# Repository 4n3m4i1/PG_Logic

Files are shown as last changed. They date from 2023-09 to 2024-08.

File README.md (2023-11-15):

# ProgrammaGull Logic
Small and open source FPGA development boards for all those still pecking for fries.  

## Hardware
Design files provided for KiCad 7.
  
### PGL Sandpiper
An education focused development platform, full of fun I/O and devices for users to learn the basics of real world FPGA development. The board centers around the Lattice iCE40-UP5k, which itself offers ample BRAM, PSRAM, 8 DSP Blocks, a PLL, and two internal oscillators.

### PGL E3
An iCE40-UP5k SG48 development board and associated programmer board.  
Designed to be embeddable and flexible enough for most projects!  
  
### PGL E6
A small embeddable Lattice iCE40-LP384 aimed at alleviating the overhead incurred when adding glue logic or general PL space into a project.

### PGL E6-NF
The same PGL E6 but with no flash, allowing smaller footprints when accompanied by some external bitstream source (MCU, external flash, other FPGA, etc..)

## Credits
Name: @slurpeecup

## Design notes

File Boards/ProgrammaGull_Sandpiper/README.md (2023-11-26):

# ProgrammaGull Sandpiper
The Sandpiper is a complete educational development platform based on the Lattice UP5K.  
Designed for students in introductory FPGA labs and other interested parties.  
A plethora of user I/O options are integrated, allowing a complete system that can  
be used anywhere with minimal setup.

## Todo
v. Alpha
- Cleanup Layout
- Assess switching PSU
- Serialize Switch Inputs (Par -> Ser)
- Swap GPIO header to manufacturable part
- No ADC Version with 2x6 PMOD
- Add encoder, maybe bring back center DPAD button?
- Consolidate BOM (3x HCS595, discrete PNP and NPN driver for 7 seg)
  
## Errata
v. Alpha
- First board run has reversed UART TX/RX LED orientation (Fixed in KiCad files)
- First board run 7 segment common anode driver transistor bases leak through 74HCS596 input protection diode, all digits are always on.

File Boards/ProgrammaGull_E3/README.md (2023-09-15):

# ProgrammaGull E3
A flexible and light development board based on the iCE40-SG48, designed for use with project icestorm and Apio.

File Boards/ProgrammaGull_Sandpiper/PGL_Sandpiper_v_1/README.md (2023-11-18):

# ProgrammaGull Logic Sandpiper
A small development board intended for introductions to FPGA development and university FPGA labs.  
A Lattice iCE40-UP5k is at the heart of the Sandpiper, offering a plethora of hard peripheral options, as well as adequate logic cells to support somewhat large projects.  
  
## Features
- 8 character 7 segment display (serial access)
- 4 direction DPAD and an additional button
- 6 pin PMOD (or GPIO), 2 GPIO with RC low pass filter aliases allowing an on board PDM DAC output
- Optional 4 input SPI ADC (ADC084S051CIMM)
- RGB LED
- 8 SPST slide switches
- 8 single color LEDs (serial access)
- FT2232HQ interface supporting both programming and PC USB <-> FPGA UART via FTDI VCOM
  
As the UP5k has limited GPIO pins for a general purpose development board serial -> parallel and in the future  
parallel to serial interfaces are implemented for the low speed high pin count I/O (7 segment displays, LED banks, etc..), this is notated by (serial access) next to a feature.  

## Software Support
Once initial prototypes arrive scripts will be released to integrate the Sandpiper into the Apio ecosystem.  
This open source assembly of tools greatly simplifies lint, build, and upload on many FPGA platforms,  
and is highly recommended for introductory users (and advanced users as well.. it's very practical!)  
  
Standard icestick workflows may also be supported, though this has yet to be seen.
  
## Errata
- First run of boards had reversed LEDs on FT2232HQ, this has been fixed in schematic and PCB

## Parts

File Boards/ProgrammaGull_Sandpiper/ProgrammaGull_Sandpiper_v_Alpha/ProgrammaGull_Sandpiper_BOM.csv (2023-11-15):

Designator | Qty | Value | Footprint | LCSC Part Number
C1, C2, C3, C4, C5, C6, C19, C21, C23, C24 | 10 | 1u | 603 | C525331
C8, C9, C11, C13, C14, C16, C18, C20, C22, C26, C28, C29, C31, C32, C34, C36, C37, C40, C41, C43, C44, C46, C47, C48, C50, C52, C54, C55, C56 | 29 | 100n | 603 | C2168880
C10, C12, C15, C17, C25, C27, C30, C33, C35 | 9 | 4u7 | 805 | C2918489
C42, C45, C49, C51, C53 | 5 | 10n | 603 | C57112
D1 | 1 | 1N4148W | SOD-123 | C81598
D2, D3, D4, D5, D6, D7, D8, D9, D11, D12 | 10 | LED | 805 | C2297
D10 | 1 | LED_ABGR | PLCC4 | C2874119
FB1, FB2 | 2 | FerriteBead_Small | 603 | C1002
P1 | 1 | USB_C_Plug_USB2.0 | Connector_USB:USB_C_Receptacle_GCT_USB4105-xx-A_16P_TopMnt_Horizontal | C963411
Q1, Q2, Q3, Q4, Q5, Q6, Q7, Q8 | 8 | MMBT2907 | SOT-23 | C106923
R1, R7, R8, R10, R12, R14, R16, R18, R20, R22, R24, R26, R28, R32, R34, R36, R37, R39, R40, R41, R42, R51, R52, R53, R63, R65, R66, R67, R68, R69, R70, R71, R72, R73, R74 | 35 | 10k | 603 | C25804
R2, R35, R54, R87, R88, R89, R90, R91 | 8 | 680R | 603 | C112310
R3, R4 | 2 | 56k | 603 | C23206
R5, R83, R84 | 3 | 100R | 603 | C22775
R6, R9, R11, R13, R15, R17, R19, R21, R23, R25, R27, R29, R55, R56, R57, R58, R59, R60, R61, R62, R64, R79, R80, R81, R82, R85, R86 | 27 | 220R | 603 | C22962
R33 | 1 | 2k2 | 603 | C4190
R38 | 1 | 12k 1% | 603 | C22790
R43, R44, R45, R46, R47, R48, R49, R50 | 8 | 383R | 603 | C5126195
SW0, SW1, SW2, SW3, SW4, SW5, SW6, SW7 | 8 | SW_Slide | SLW-121586-5A-D | C2887261
SW9, SW10, SW11, SW12, SW14 | 5 | SW_Push | Alps_SKQGAKE010 | C127478
U2 | 1 | SN74LVC1G126DCKR | SC70 | C88039
U3, U12 | 2 | 74HCS596 | TSSOP-16_4.4x5mm_P0.65mm | C2871501
U4 | 1 | MIC5504-1.2YM5 | SOT-23-5 | C81462
U6 | 1 | 93LCxxAxxOT | SOT-23-6 | C190271
U7 | 1 | FT2232HQ | QFN-64-1EP_9x9mm_P0.5mm_EP4.35x4.35mm | C193662
U8, U10 | 2 | Display_7Seg | MHDA3641SRBW | C401125
U13 | 1 | 74AHCS595 | TSSOP-16_4.4x5mm_P0.65mm | C2864509
U14 | 1 | W25Q32JVSS | SOIC-8_5.23x5.23mm_P1.27mm | C179173
U15 | 1 | AMS1117-3.3 | SOT-223-3_TabPin2 | C6186
X1 | 1 | SG-210STF | Oscillator_SMD_SeikoEpson_SG210-4Pin_2.5x2.0mm | C2831468

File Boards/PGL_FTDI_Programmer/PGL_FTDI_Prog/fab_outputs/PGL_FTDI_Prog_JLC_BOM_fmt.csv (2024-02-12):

Designator | Qty | Value | Footprint | LCSC Part Number
C1, C2, C9, C14, C26 | 5 | 1u | Capacitor_SMD:C_0402_1005Metric | C52923
C4, C5, C6, C10, C12, C15, C16, C18, C19, C24, C25 | 11 | 100n | Capacitor_SMD:C_0402_1005Metric | C307331
C7, C8, C11, C13, C17, C27 | 6 | 4u7 | Capacitor_SMD:C_0805_2012Metric | C1779
C22, C23 | 2 | 33p C0G | Capacitor_SMD:C_0402_1005Metric | C1562
D2, D3 | 2 | LED | LED_SMD:LED_0805_2012Metric | C2297
FB1, FB2 | 2 | FerriteBead_Small | Inductor_SMD:L_0603_1608Metric | C1002
P1 | 1 | USB_C_Plug_USB2.0 | Connector_USB:USB_C_Receptacle_GCT_USB4105-xx-A_16P_TopMnt_Horizontal | C963413
R1, R3, R5, R6 | 4 | 10k | Resistor_SMD:R_0603_1608Metric | C25804
R2 | 1 | 2k2 | Resistor_SMD:R_0603_1608Metric | C4190
R4 | 1 | 12k 1% | Resistor_SMD:R_0603_1608Metric | C22790
R7, R8 | 2 | 56k | Resistor_SMD:R_0603_1608Metric | C23206
R11, R14 | 2 | 330R | Resistor_SMD:R_0603_1608Metric | C23151
U1 | 1 | XC6206PxxxMR | Package_TO_SOT_SMD:SOT-23-3 | C5446
U4 | 1 | 93LCxxAxxOT | Package_TO_SOT_SMD:SOT-23-6 | C190271
U5 | 1 | FT2232HQ | Package_DFN_QFN:QFN-64-1EP_9x9mm_P0.5mm_EP4.35x4.35mm | C193662
Y1 | 1 | 12.000 MHz, C9002 | Crystal:Crystal_SMD_3225-4Pin_3.2x2.5mm | C9002

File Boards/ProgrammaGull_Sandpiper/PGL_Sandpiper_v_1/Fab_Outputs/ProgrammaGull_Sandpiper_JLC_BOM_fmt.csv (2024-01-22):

Designator | Qty | Value | Footprint | LCSC Part Number
C1, C2, C3, C4, C5, C6, C19, C21, C23, C24, C41, C43, C44 | 13 | 1u | Capacitor_SMD:C_0603_1608Metric | C15849
C7, C8, C9, C11, C13, C14, C16, C18, C20, C22, C26, C28, C29, C31, C32, C34, C36, C37, C40, C46, C47, C48, C50, C52, C54, C55, C56, C60, C61 | 29 | 100n | Capacitor_SMD:C_0603_1608Metric | C14663
C10, C12, C15, C17, C25, C27, C30, C33, C35, C57, C58, C59 | 12 | 4u7 | Capacitor_SMD:C_0805_2012Metric | C1779
C38, C39, C42, C45, C49, C51, C53 | 7 | 10n | Capacitor_SMD:C_0603_1608Metric | C57112
D1 | 1 | 1N4148W | Diode_SMD:D_SOD-123 | C81598
D2, D3, D4, D5, D6, D7, D8, D9, D11, D12 | 10 | LED | LED_SMD:LED_0805_2012Metric | C2297
D10 | 1 | LED_ABGR | LED_SMD:LED_Cree-PLCC4_2x2mm_CW | C2874119
FB1, FB2 | 2 | FerriteBead_Small | Inductor_SMD:L_0603_1608Metric | C1002
J1 | 1 | Conn_02x14_Odd_Even | Connector_PinSocket_2.54mm:PinSocket_2x14_P2.54mm_Horizontal | C2897434
P1 | 1 | USB_C_Plug_USB2.0 | Connector_USB:USB_C_Receptacle_GCT_USB4105-xx-A_16P_TopMnt_Horizontal | C963411
Q1, Q2, Q3, Q4, Q5, Q6, Q7, Q8 | 8 | S9012 2T1 | Package_TO_SOT_SMD:SOT-23 | C8543
R1, R7, R8, R10, R12, R14, R16, R18, R20, R22, R24, R26, R28, R30, R31, R32, R34, R36, R37, R39, R40, R41, R42, R51, R52, R53, R63, R65, R66, R67, R68, R69, R70, R71, R72, R73, R74, R75, R76, R77, R78, R79, R81 | 43 | 10k | Resistor_SMD:R_0603_1608Metric | C25804
R2, R33, R35, R54, R87, R88, R89, R90, R91 | 9 | 2k2 | Resistor_SMD:R_0603_1608Metric | C4190
R3, R4 | 2 | 56k | Resistor_SMD:R_0603_1608Metric | C23206
R5, R83, R84 | 3 | 100R | Resistor_SMD:R_0603_1608Metric | C22775
R6, R9, R11, R13, R15, R17, R19, R21 | 8 | 220R | Resistor_SMD:R_0603_1608Metric | C22962
R23, R25, R27, R29, R64, R80, R92, R93, R94, R95, R96, R97, R98, R99 | 14 | 220R | Resistor_SMD:R_0402_1005Metric | C25091
R38 | 1 | 12k 1% | Resistor_SMD:R_0603_1608Metric | C22790
R43, R44, R45, R46, R47, R48, R49, R50 | 8 | 390R | Resistor_SMD:R_0603_1608Metric | C23151
R55, R56, R57, R58, R59, R60, R61, R62 | 8 | 400R | Resistor_SMD:R_0603_1608Metric | C23151
R85, R86 | 2 | 330R | Resistor_SMD:R_0603_1608Metric | C23151
SW0, SW1, SW2, SW3, SW4, SW5, SW6, SW7 | 8 | ~ | ProgrammaGull_Logic:SLW-121586-5A-D | C2887261
SW8 | 1 | RotaryEncoder_Switch | Rotary_Encoder:RotaryEncoder_Alps_EC11E-Switch_Vertical_H20mm | C2991196
SW9, SW10, SW11, SW12, SW13 | 5 | SW_Push | ProgrammaGull_Logic:TSC015A05518A | C2888975
U2 | 1 | SN74LVC1G126DCKR | ProgrammaGull_Logic:SC70 | C88039
U3, U12, U13 | 3 | 74HCT595 | Package_DFN_QFN:DHVQFN-16-1EP_2.5x3.5mm_P0.5mm_EP1x2mm | C3303720
U4 | 1 | MIC5504-1.2YM5 | Package_TO_SOT_SMD:SOT-23-5 | C81462
U6 | 1 | 93LCxxAxxOT | Package_TO_SOT_SMD:SOT-23-6 | C190271
U7 | 1 | FT2232HQ | Package_DFN_QFN:QFN-64-1EP_9x9mm_P0.5mm_EP4.35x4.35mm | C193662
U8, U10 | 2 | ~ | ProgrammaGull_Logic:MHDA3641SRBW | C401125
U9 | 1 | 74HC165 | Package_SO:TSSOP-16_4.4x5mm_P0.65mm | C43420
U14 | 1 | W25Q32JVSS | Package_SO:SOIC-8_5.23x5.23mm_P1.27mm | C179173
U15 | 1 | AMS1117-3.3 | Package_TO_SOT_SMD:SOT-223-3_TabPin2 | C6186
X1 | 1 | SG-210STF | Oscillator:Oscillator_SMD_SeikoEpson_SG210-4Pin_2.5x2.0mm | C2831468

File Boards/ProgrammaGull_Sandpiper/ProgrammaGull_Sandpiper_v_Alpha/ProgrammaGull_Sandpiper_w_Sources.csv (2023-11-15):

# | Reference | Qty | Value | Footprint | DNP | Source | Unit Price | Price @ Qty | Assembly Fee | Extended Price | Assembly | P/N | Link
1 | C1, C2, C3, C4, C5, C6, C19, C21, C23, C24 | 10 | 1u | Capacitor_SMD:C_0603_1608Metric |  | JLC | 0.0076 | 0.076 | 3 | 3.076 | JLC | C525331 | https://jlcpcb.com/partdetail/543458-FS18B105K6R3PBG/C525331
2 | C7 | 1 | 10u | Capacitor_SMD:C_0805_2012Metric | YES | JLC |  | 0 | 0 | 0 | JLC
3 | C8, C9, C11, C13, C14, C16, C18, C20, C22, C26, C28, C29, C31, C32, C34, C36, C37, C38, C39, C40, C41, C43, C44, C46, C47, C48, C50, C52, C54, C55, C56 | 31 | 100n | Capacitor_SMD:C_0603_1608Metric |  | JLC | 0.0104 | 0.3224 | 3 | 3.3224 | JLC | C2168880 | https://jlcpcb.com/partdetail/-06035C104K4T2A/C2168880
4 | C10, C12, C15, C17, C25, C27, C30, C33, C35 | 9 | 4u7 | Capacitor_SMD:C_0805_2012Metric |  | JLC | 0.0075 | 0.0675 | 3 | 3.0675 | JLC | C2918489 | https://jlcpcb.com/partdetail/3220341-CS2012X5R475K250NRE/C2918489
5 | C42, C45, C49, C51, C53 | 5 | 10n | Capacitor_SMD:C_0603_1608Metric |  | JLC | 0.0022 | 0.011 | 0 | 0.011 | JLC | C57112 | https://jlcpcb.com/partdetail/58143-0603B103K500NT/C57112
6 | D1 | 1 | 1N4148W | Diode_SMD:D_SOD-123 |  | JLC | 0.0098 | 0.0098 | 0 | 0.0098 | JLC | C81598 | https://jlcpcb.com/partdetail/st_semtech-1N4148W/C81598
7 | D2, D3, D4, D5, D6, D7, D8, D9, D11, D12 | 10 | LED | LED_SMD:LED_0805_2012Metric |  | JLC | 0.0125 | 0.125 | 0 | 0.125 | JLC | C2297 | https://jlcpcb.com/partdetail/Hubei_KentoElec-KT0805G/C2297
8 | D10 | 1 | LED_ABGR | LED_SMD:LED_Cree-PLCC4_2x2mm_CW |  | JLC | 0.0131 | 0.0131 | 3 | 3.0131 | JLC | C2874119 | https://jlcpcb.com/partdetail/3078831-NH_Z1921RGBASF/C2874119
9 | FB1, FB2 | 2 | FerriteBead_Small | Inductor_SMD:L_0603_1608Metric |  | JLC | 0.0045 | 0.0045 | 0 | 0.009 | JLC | C1002 | https://jlcpcb.com/partdetail/Sunlord-GZ1608D601TF/C1002
10 | J4 | 1 | Conn_01x22_Socket | Connector_PinSocket_2.54mm:PinSocket_1x22_P2.54mm_Horizontal |  | N/A |  | 0 | 0 | 0 | Hand
11 | P1 | 1 | USB_C_Plug_USB2.0 | Connector_USB:USB_C_Receptacle_GCT_USB4105-xx-A_16P_TopMnt_Horizontal |  | JLC | 0.1544 | 0.1544 | 3 | 3.1544 | JLC | C963411 | https://jlcpcb.com/partdetail/gswitch-GT_USB7010AW/C963411
12 | Q1, Q2, Q3, Q4, Q5, Q6, Q7, Q8 | 8 | MMBT2907 | Package_TO_SOT_SMD:SOT-23 |  | JLC | 0.0163 | 0.1304 | 3 | 3.1304 | JLC | C106923 | https://jlcpcb.com/partdetail/DiodesIncorporated-MMBT2907A_7F/C106923
13 | R1, R7, R8, R10, R12, R14, R16, R18, R20, R22, R24, R26, R28, R30, R32, R34, R36, R37, R39, R40, R41, R42, R51, R52, R53, R63, R65, R66, R67, R68, R69, R70, R71, R72, R73, R74, R75, R78 | 38 | 10k | Resistor_SMD:R_0603_1608Metric |  | JLC | 0.0008 | 0.0304 | 0 | 0.0304 | JLC | C25804 | https://jlcpcb.com/partdetail/26547-0603WAF1002T5E/C25804
14 | R2, R35, R54, R87, R88, R89, R90, R91 | 8 | 680R | Resistor_SMD:R_0603_1608Metric |  | JLC | 0.0011 | 0.0088 | 3 | 3.0088 | JLC | C112310 | https://jlcpcb.com/partdetail/Yageo-RC0603FR07680RL/C112310
15 | R3, R4 | 2 | 56k | Resistor_SMD:R_0603_1608Metric |  | JLC | 0.001 | 0.002 | 0 | 0.002 | JLC | C23206 | https://jlcpcb.com/partdetail/23933-0603WAF5602T5E/C23206
16 | R5, R83, R84 | 3 | 100R | Resistor_SMD:R_0603_1608Metric |  | JLC | 0.0009 | 0.0027 | 0 | 0.0027 | JLC | C22775 | https://jlcpcb.com/partdetail/23502-0603WAF1000T5E/C22775
17 | R6, R9, R11, R13, R15, R17, R19, R21, R23, R25, R27, R29, R31, R55, R56, R57, R58, R59, R60, R61, R62, R64, R79, R80, R81, R82, R85, R86 | 28 | 220R | Resistor_SMD:R_0603_1608Metric |  | JLC | 0.0009 | 0.0252 | 0 | 0.0252 | JLC | C22962 | https://jlcpcb.com/partdetail/23689-0603WAF2200T5E/C22962
18 | R33, R76, R77 | 3 | 2k2 | Resistor_SMD:R_0603_1608Metric |  | JLC | 0.0009 | 0.0027 | 0 | 0.0027 | JLC | C4190 | https://jlcpcb.com/partdetail/4597-0603WAF2201T5E/C4190
19 | R38 | 1 | 12k 1% | Resistor_SMD:R_0603_1608Metric |  | JLC | 0.0009 | 0.0009 | 0 | 0.0009 | JLC | C22790 | https://jlcpcb.com/partdetail/23517-0603WAF1202T5E/C22790
20 | R43, R44, R45, R46, R47, R48, R49, R50 | 8 | 383R | Resistor_SMD:R_0603_1608Metric |  | JLC | 0.0008 | 0.0064 | 3 | 3.0064 | JLC | C5126195 | https://jlcpcb.com/partdetail/Fojan-FRC0603F3830TS/C5126195
21 | SW0, SW1, SW2, SW3, SW4, SW5, SW6, SW7 | 8 | ~ | ProgrammaGull_Logic:SLW-121586-5A-D |  | JLC | 0.0206 | 0.1648 | 3 | 3.1648 | JLC? | C2887261 | https://jlcpcb.com/partdetail/ShouHan-SS12F44G4/C2887261
22 | SW9, SW10, SW11, SW12, SW13, SW14 | 6 | SW_Push | ProgrammaGull_Logic:Alps_SKQGAKE010 |  | JLC | 0.0677 | 0.4062 | 3 | 3.4062 | JLC | C127478 | https://jlcpcb.com/partdetail/Alpsalpine-SKQGAKE010/C127478
23 | SW15 | 1 | RotaryEncoder | Rotary_Encoder:RotaryEncoder_Bourns_Vertical_PEC12R-3xxxF-Nxxxx | Yes | N/A |  | 0 | 0 | 0 | N/A
24 | U1 | 1 | ICE40UP5K-SG48ITR | Package_DFN_QFN:QFN-48-1EP_7x7mm_P0.5mm_EP5.6x5.6mm |  | Mouser | 8.89 | 8.89 | 0 | 8.89 | Hand
25 | U2 | 1 | SN74LVC1G126DCKR | ProgrammaGull_Logic:SC70 |  | JLC | 0.0702 | 0.0702 | 3 | 3.0702 | JLC | C88039 | https://jlcpcb.com/partdetail/TexasInstruments-SN74LVC1G126DCKR/C88039
26 | U3, U12 | 2 | 74HC596 | Package_SO:TSSOP-16_4.4x5mm_P0.65mm |  | JLC | 0.2363 | 0.4726 | 3 | 3.4726 | JLC | C2871501 | https://jlcpcb.com/partdetail/TexasInstruments-SN74HCS596PWR/C2871501
27 | U4 | 1 | MIC5504-1.2YM5/TLV70212DBVR | Package_TO_SOT_SMD:SOT-23-5 |  | JLC | 0.119 | 0.119 | 3 | 3.119 | JLC | C81462 | https://jlcpcb.com/partdetail/TexasInstruments-TLV70212DBVR/C81462
28 | U5 | 1 | MIC5504-2.5YM5 | Package_TO_SOT_SMD:SOT-23-5 | Yes | Mouser | 0.12 | 0.12 | 0 | 0.12 | Hand
29 | U6 | 1 | 93LCxxAxxOT | Package_TO_SOT_SMD:SOT-23-6 |  | JLC | 0.6818 | 0.6818 | 3 | 3.6818 | JLC | C190271 | https://jlcpcb.com/partdetail/MicrochipTech-93LC56BT_IOT/C190271
30 | U7 | 1 | FT2232HQ | Package_DFN_QFN:QFN-64-1EP_9x9mm_P0.5mm_EP4.35x4.35mm |  | JLC | 8.0998 | 8.0998 | 3 | 11.0998 | JLC | C193662 | https://jlcpcb.com/partdetail/Ftdi-FT2232HQREEL/C193662
31 | U8, U10 | 2 | ~ | ProgrammaGull_Logic:MHDA3641SRBW |  | JLC | 0.7335 | 1.467 | 0 | 1.467 | Hand | C401125 | https://jlcpcb.com/partdetail/Meihua-MHDA3641SRBW/C401125
32 | U11 | 1 | ADC084S051CIMM/NOPB | Package_SO:VSSOP-10_3x3mm_P0.5mm |  | Mouser | 2.79 | 2.79 | 0 | 2.79 | Hand
33 | U13 | 1 | 74AHC595 | Package_SO:TSSOP-16_4.4x5mm_P0.65mm |  | JLC | 0.3978 | 0.3978 | 3 | 3.3978 | JLC | C2864509 | https://jlcpcb.com/partdetail/TexasInstruments-SN74HCS595QPWRQ1/C2864509
34 | U14 | 1 | W25Q32JVSS | Package_SO:SOIC-8_5.23x5.23mm_P1.27mm |  | JLC | 0.2347 | 0.2347 | 3 | 3.2347 | JLC | C179173 | https://jlcpcb.com/partdetail/WinbondElec-W25Q32JVSSIQ/C179173
35 | U15 | 1 | AMS1117-3.3 | Package_TO_SOT_SMD:SOT-223-3_TabPin2 |  | JLC | 0.129 | 0.129 | 0 | 0.129 | JLC | C6186 | https://jlcpcb.com/partdetail/Advanced_MonolithicSystems-AMS1117_33/C6186
36 | X1 | 1 | SG-210STF | Oscillator:Oscillator_SMD_SeikoEpson_SG210-4Pin_2.5x2.0mm |  | JLC | 0.4777 | 0.4777 | 3 | 3.4777 | JLC | C2831468 | https://jlcpcb.com/partdetail/Jwt-YM4012M00033T8188099/C2831468
 |  |  |  |  |  |  |  | Parts Cost | Total Assembly $ | Price / 1 + Asm |  |  | PCB QTY | PCB Cost | $ / PCB
 |  |  |  |  |  |  |  | 25.5138 | 54 | 79.5183 |  |  | 5 | 7 | 1.4
 |  |  |  |  |  |  |  |  |  |  |  |  | 10 | 13 | 1.3
 |  |  |  |  |  |  |  |  | Qty | Price / 5 | Price Avg / 1
 |  |  |  |  |  |  |  |  | 5 | 181.569 | 36.3138
 |  |  |  |  |  |  |  |  |  |  |  |  | Total Cost / 5 | Total Avg / 1
 |  |  |  |  |  |  |  |  |  |  |  |  | 188.569 | 37.7138

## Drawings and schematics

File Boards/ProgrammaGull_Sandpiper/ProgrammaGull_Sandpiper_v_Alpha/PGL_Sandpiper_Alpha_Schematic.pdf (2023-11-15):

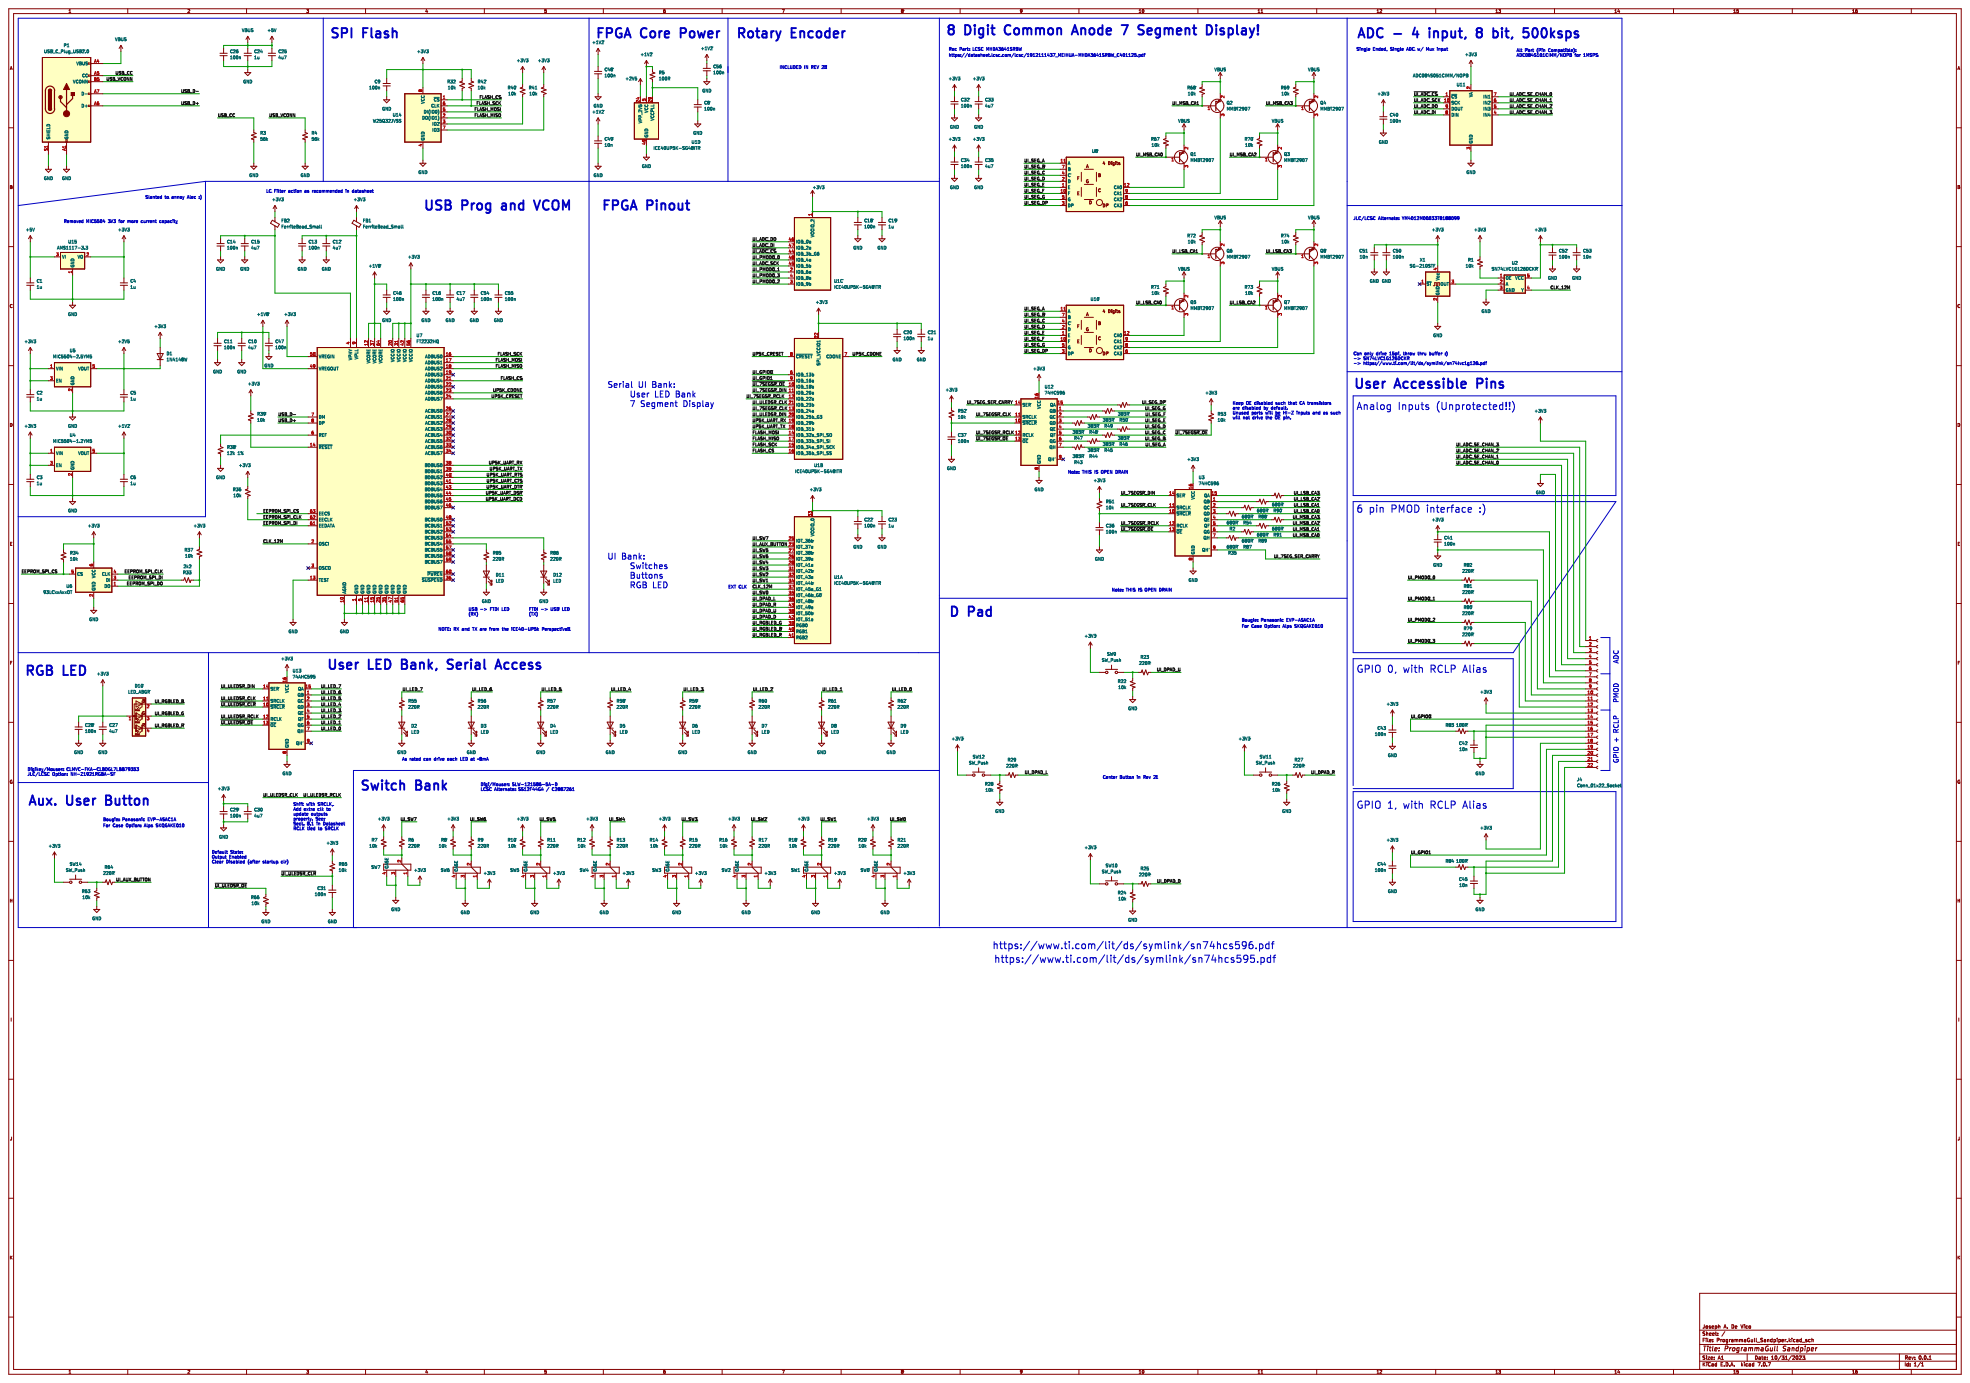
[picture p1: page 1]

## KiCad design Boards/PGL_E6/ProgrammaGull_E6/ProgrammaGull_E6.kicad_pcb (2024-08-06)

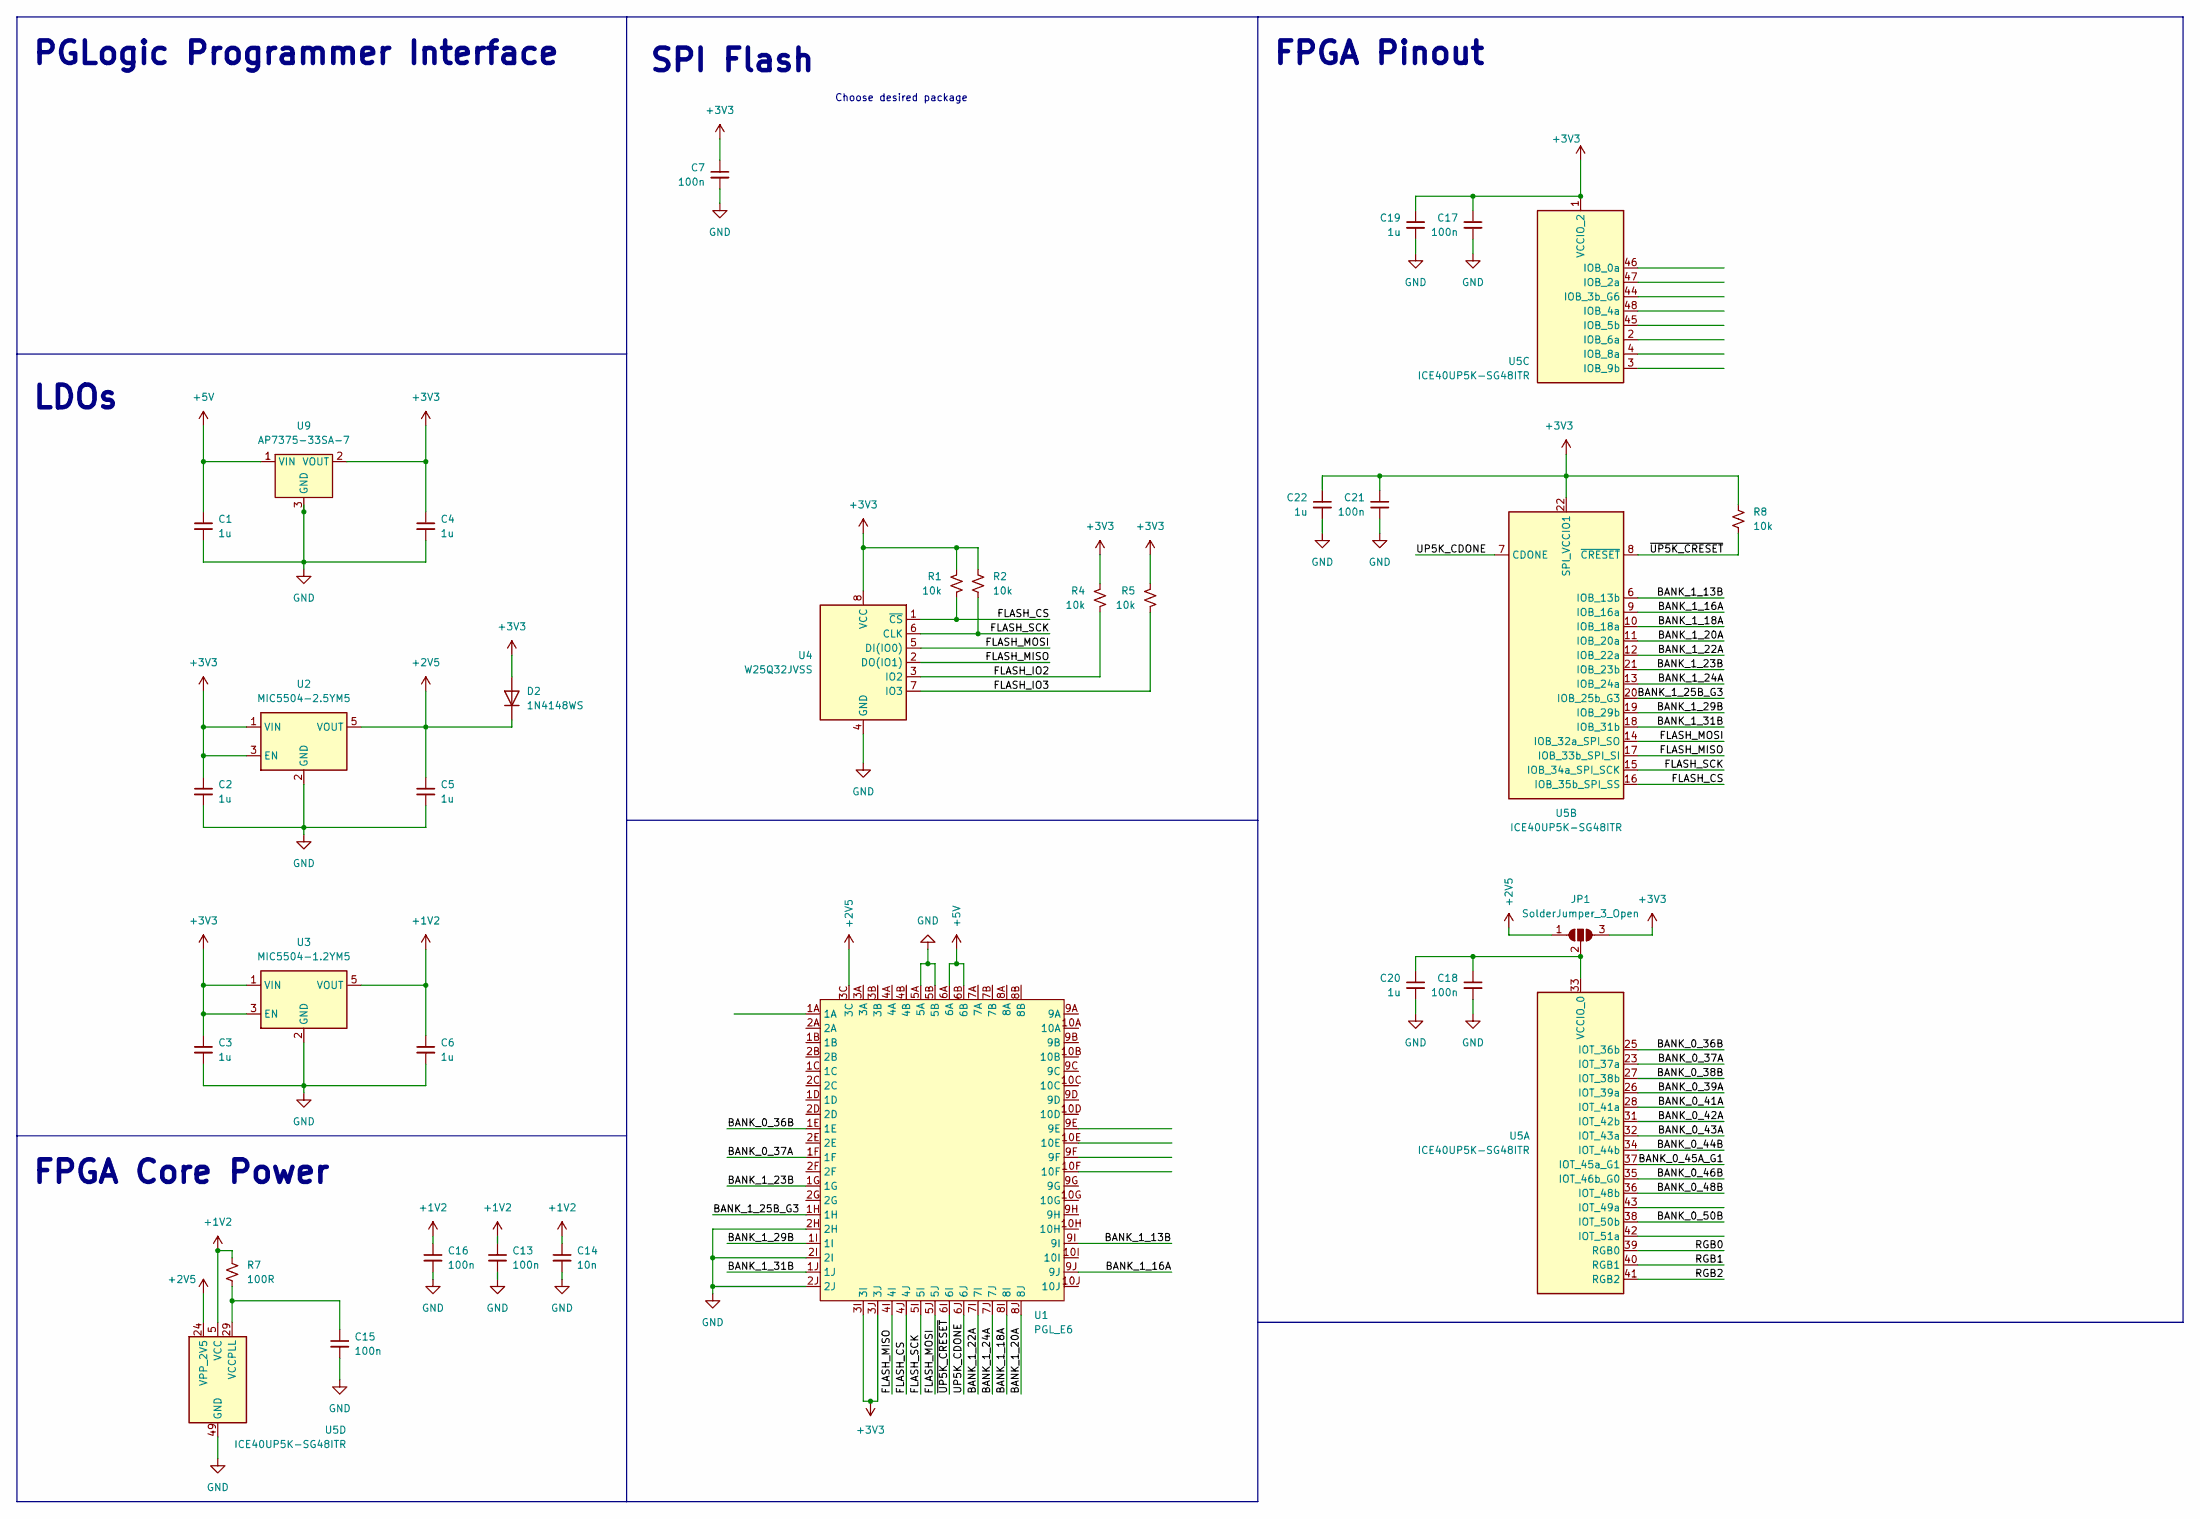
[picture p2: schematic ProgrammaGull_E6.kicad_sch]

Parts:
C1, C2, C3, C4, C5, C6, C19, C20, C22: 1u; C_0603_1608Metric
C7, C13, C15, C16, C17, C18, C21: 100n; C_0603_1608Metric
C14: 10n; C_0603_1608Metric
D2: 1N4148WS; D_SOD-323
JP1: SolderJumper_3_Open; SolderJumper-3_P2.0mm_Open_TrianglePad1.0x1.5mm
R1, R2, R4, R5, R8: 10k; R_0603_1608Metric
R7: 100R; R_0603_1608Metric
U1: PGL_E6
U2: MIC5504-2.5YM5; SOT-23-5
U3: MIC5504-1.2YM5; SOT-23-5
U4: W25Q32JVSS; SOIC-8_5.23x5.23mm_P1.27mm
U5: ICE40UP5K-SG48ITR; QFN-48-1EP_7x7mm_P0.5mm_EP5.6x5.6mm
U9: AP7375-33SA-7; SOT-23-3

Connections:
+1V2: C6.1, C13.1, C14.1, C16.1, R7.2, U3.5 (VOUT), U5.5 (VCC), U5.30 (VCC)
+2V5: C5.1, D2.1 (K), JP1.1 (A), U1.3C, U2.5 (VOUT), U5.24 (VPP_2V5)
+3V3: C2.1, C3.1, C4.1, C7.1, C17.1, C19.1, C21.1, C22.1, D2.2 (A), JP1.3 (B), R1.2, R2.2, R4.2, R5.2, R8.2, U1.3I, U1.3J, U2.1 (VIN), U2.3 (EN), U3.1 (VIN), U3.3 (EN), U4.8 (VCC), U5.1 (VCCIO_2), U5.22 (SPI_VCCIO1), U9.2 (VOUT)
+5V: C1.1, U1.6A, U1.6B, U9.1 (VIN)
/BANK_0_36B: U1.1E, U5.25 (IOT_36b)
/BANK_0_37A: U1.1F, U5.23 (IOT_37a)
/BANK_0_38B: U5.27 (IOT_38b)
/BANK_0_39A: U5.26 (IOT_39a)
/BANK_0_41A: U5.28 (IOT_41a)
/BANK_0_42A: U5.31 (IOT_42b)
/BANK_0_43A: U5.32 (IOT_43a)
/BANK_0_44B: U5.34 (IOT_44b)
/BANK_0_45A_G1: U5.37 (IOT_45a_G1)
/BANK_0_46B: U5.35 (IOT_46b_G0)
/BANK_0_48B: U5.36 (IOT_48b)
/BANK_0_50B: U5.38 (IOT_50b)
/BANK_1_13B: U1.9I, U5.6 (IOB_13b)
/BANK_1_16A: U1.9J, U5.9 (IOB_16a)
/BANK_1_18A: U1.8I, U5.10 (IOB_18a)
/BANK_1_20A: U1.8J, U5.11 (IOB_20a)
/BANK_1_22A: U1.7I, U5.12 (IOB_22a)
/BANK_1_23B: U1.1G, U5.21 (IOB_23b)
/BANK_1_24A: U1.7J, U5.13 (IOB_24a)
/BANK_1_25B_G3: U1.1H, U5.20 (IOB_25b_G3)
/BANK_1_29B: U1.1I, U5.19 (IOB_29b)
/BANK_1_31B: U1.1J, U5.18 (IOB_31b)
/FLASH_CS: R1.1, U1.4J, U4.1 (~CS), U5.16 (IOB_35b_SPI_SS)
/FLASH_IO2: R4.1, U4.3 (IO2)
/FLASH_IO3: R5.1, U4.7 (IO3)
/FLASH_MISO: U1.4I, U4.2 (DO(IO1)), U5.17 (IOB_33b_SPI_SI)
/FLASH_MOSI: U1.5J, U4.5 (DI(IO0)), U5.14 (IOB_32a_SPI_SO)
/FLASH_SCK: R2.1, U1.5I, U4.6 (CLK), U5.15 (IOB_34a_SPI_SCK)
/RGB0: U5.39 (RGB0)
/RGB1: U5.40 (RGB1)
/RGB2: U5.41 (RGB2)
/UP5K_CDONE: U1.6J, U5.7 (CDONE)
/~UP5K_CRESET: R8.1, U1.6I, U5.8 (~CRESET)
GND: C1.2, C2.2, C3.2, C4.2, C5.2, C6.2, C7.2, C13.2, C14.2, C15.2, C16.2, C17.2, C18.2, C19.2, C20.2, C21.2, C22.2, U1.2H, U1.2I, U1.2J, U1.5A, U1.5B, U2.2 (GND), U3.2 (GND), U4.4 (GND), U5.49 (GND), U9.3 (GND)
unnamed: C18.1, C20.1, JP1.2 (C), U5.33 (VCCIO_0)
unnamed: C15.1, R7.1, U5.29 (VCCPLL)

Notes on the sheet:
LDOs
SPI Flash
PGLogic Programmer Interface
FPGA Core Power
Choose desired package
FPGA Pinout

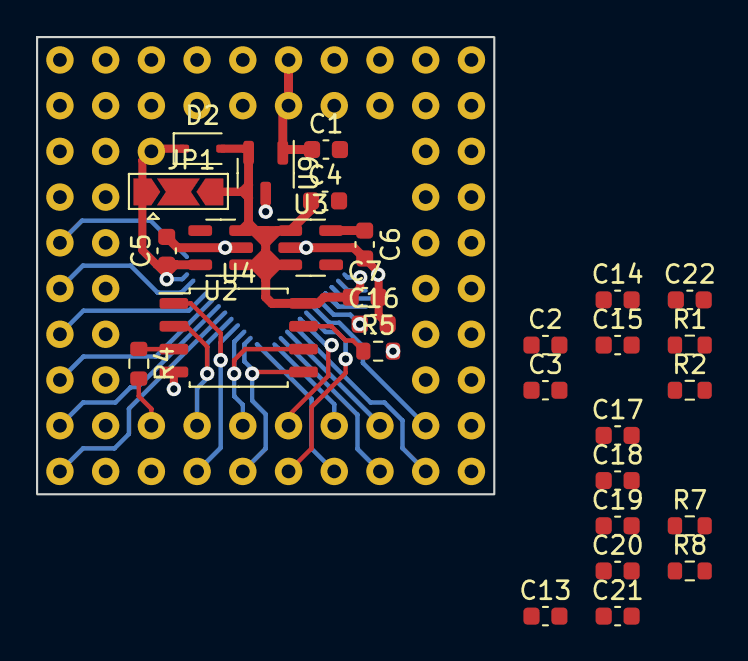
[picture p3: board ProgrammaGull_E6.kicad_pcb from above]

Board: 4 copper layers, 25.4 x 25.4 mm, 31 parts (1 on the bottom side), 27 nets.

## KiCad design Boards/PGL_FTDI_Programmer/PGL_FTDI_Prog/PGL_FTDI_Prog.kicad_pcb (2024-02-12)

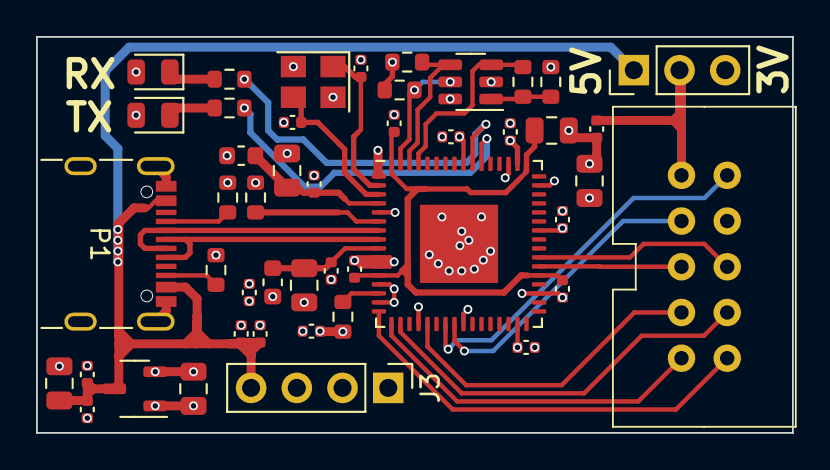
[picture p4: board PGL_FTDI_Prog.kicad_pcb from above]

Board: 4 copper layers, 42.0 x 22.0 mm, 46 parts (0 on the bottom side), 31 nets.

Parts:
C1, C2, C9, C14, C26: 1u; C_0402_1005Metric
C4, C5, C6, C10, C12, C15, C16, C18, C19, C24, C25: 100n; C_0402_1005Metric
C7, C8, C11, C13, C17, C27: 4u7; C_0805_2012Metric
C22, C23: 33p C0G; C_0402_1005Metric
D2, D3: LED; LED_0805_2012Metric
FB1, FB2: FerriteBead_Small; L_0603_1608Metric
J1: Conn_01x03_Pin; PinHeader_1x03_P2.54mm_Vertical
J3: Conn_01x04; PinHeader_1x04_P2.54mm_Vertical
P1: USB_C_Plug_USB2.0; USB_C_Receptacle_GCT_USB4105-xx-A_16P_TopMnt_Horizontal
R1, R3, R5, R6: 10k; R_0603_1608Metric
R2: 2k2; R_0603_1608Metric
R4: 12k 1%; R_0603_1608Metric
R7, R8: 56k; R_0603_1608Metric
R11, R14: 330R; R_0603_1608Metric
U1: XC6206PxxxMR; SOT-23-3
U4: 93LCxxAxxOT; SOT-23-6
U5: FT2232HQ; QFN-64-1EP_9x9mm_P0.5mm_EP4.35x4.35mm
U7: PG_Logic_10_Pin_Tag_Connect_Programmer_Header; CH87102V200
Y1: 12.000 MHz, C9002; Crystal_SMD_3225-4Pin_3.2x2.5mm

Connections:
+1V8: C4.1, C7.1, C10.1, C15.1, U5.12 (VCORE), U5.37 (VCORE), U5.49 (VREGOUT), U5.64 (VCORE)
+3V3: C1.1, C16.1, C17.1, C18.1, C19.1, C25.1, C26.1, C27.1, D2.2 (A), D3.2 (A), FB1.2, FB2.2, J1.3, J3.2, R1.2, R3.2, R5.2, R6.2, U1.2 (VO), U4.6 (VCC), U5.20 (VCCIO), U5.31 (VCCIO), U5.42 (VCCIO), U5.50 (VREGIN), U5.56 (VCCIO)
+5V: C6.1, C9.1, C11.1, C14.1, C24.1, J1.1, J3.4, P1.A4 (VBUS), P1.A9 (VBUS), P1.B4 (VBUS), P1.B9 (VBUS), U1.3 (VI)
/EEPROM_SPI_CLK: R5.1, U4.4 (CLK), U5.62 (EECLK)
/EEPROM_SPI_CS: R1.1, U4.5 (CS), U5.63 (EECS)
/EEPROM_SPI_DI: R2.2, U4.3 (DI), U5.61 (EEDATA)
/EEPROM_SPI_DO: R2.1, R3.1, U4.1 (DO)
/FLASH_CS: U5.21 (ADBUS4), U7.7 (~F_CS)
/FLASH_MISO: U5.18 (ADBUS2), U7.8 (F_MISO)
/FLASH_MOSI: U5.17 (ADBUS1), U7.9 (F_MOSI)
/FLASH_SCK: U5.16 (ADBUS0), U7.10 (F_SCK)
/UP5K_CDONE: U5.23 (ADBUS6), U7.2 (CDONE)
/UP5K_CRESET: U5.24 (ADBUS7), U7.3 (~CRESET)
/UP5K_UART_RX: U5.38 (BDBUS0), U7.5 (UA_RX)
/UP5K_UART_TX: U5.39 (BDBUS1), U7.6 (UA_TX)
/USB_CC: P1.A5 (CC), R7.2
/USB_D+: P1.A6 (D+), U5.8 (DP)
/USB_D-: P1.A7 (D-), U5.7 (DM)
/USB_VCONN: P1.B5 (VCONN), R8.2
/XIN: C22.1, U5.2 (OSCI), Y1.1
/XOUT: C23.1, U5.3 (OSCO), Y1.3
GND: C1.2, C2.2, C4.2, C5.2, C6.2, C7.2, C8.2, C9.2, C10.2, C11.2, C12.2, C13.2, C14.2, C15.2, C16.2, C17.2, C18.2, C19.2, C22.2, C23.2, C24.2, C25.2, C26.2, C27.2, J3.1, J3.3, P1.A1 (GND), P1.A12 (GND), P1.B1 (GND), P1.B12 (GND), P1.S1 (SHIELD), R4.1, R7.1, R8.1, U1.1 (GND), U4.2 (GND), U5.1 (GND), U5.5 (GND), U5.10 (AGND), U5.11 (GND), U5.13 (TEST), U5.15 (GND), U5.25 (GND), U5.35 (GND), U5.47 (GND), U5.51 (GND), U5.65 (GND), U7.4 (GND), Y1.2, Y1.4
unnamed: D2.1 (K), R11.1
unnamed: D3.1 (K), R14.1
unnamed: C2.1, J1.2, U7.1 (5V)
unnamed: R14.2, U5.54 (BCBUS3)
unnamed: R11.2, U5.55 (BCBUS4)
unnamed: R4.2, U5.6 (REF)
unnamed: C5.1, C8.1, FB1.1, U5.4 (VPHY)
unnamed: C12.1, C13.1, FB2.1, U5.9 (VPLL)
unnamed: R6.1, U5.14 (~RESET)

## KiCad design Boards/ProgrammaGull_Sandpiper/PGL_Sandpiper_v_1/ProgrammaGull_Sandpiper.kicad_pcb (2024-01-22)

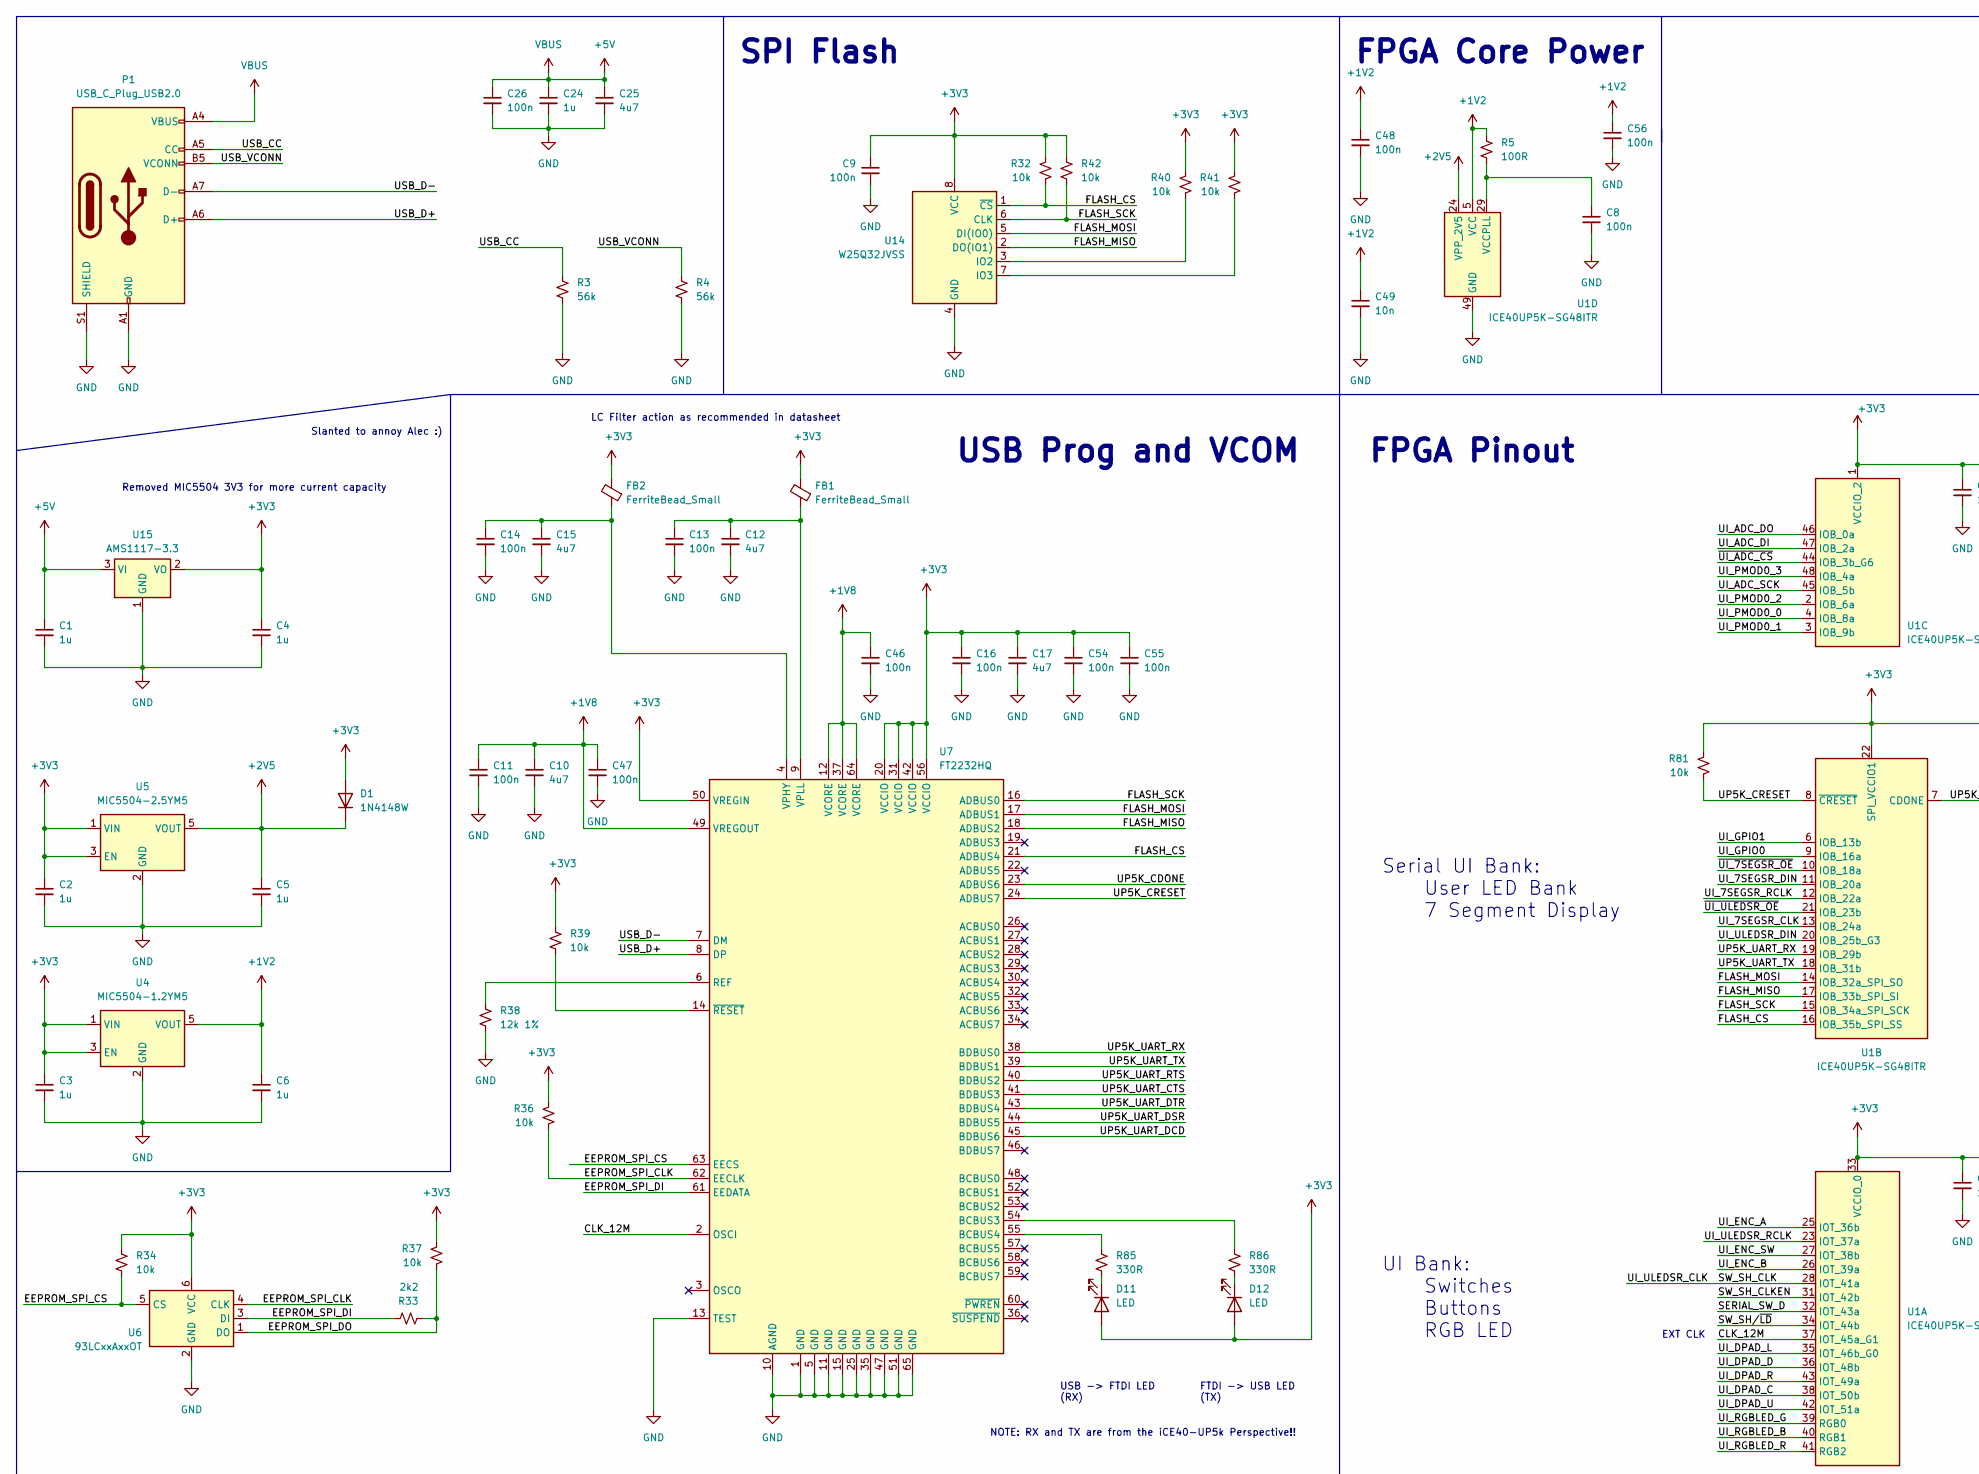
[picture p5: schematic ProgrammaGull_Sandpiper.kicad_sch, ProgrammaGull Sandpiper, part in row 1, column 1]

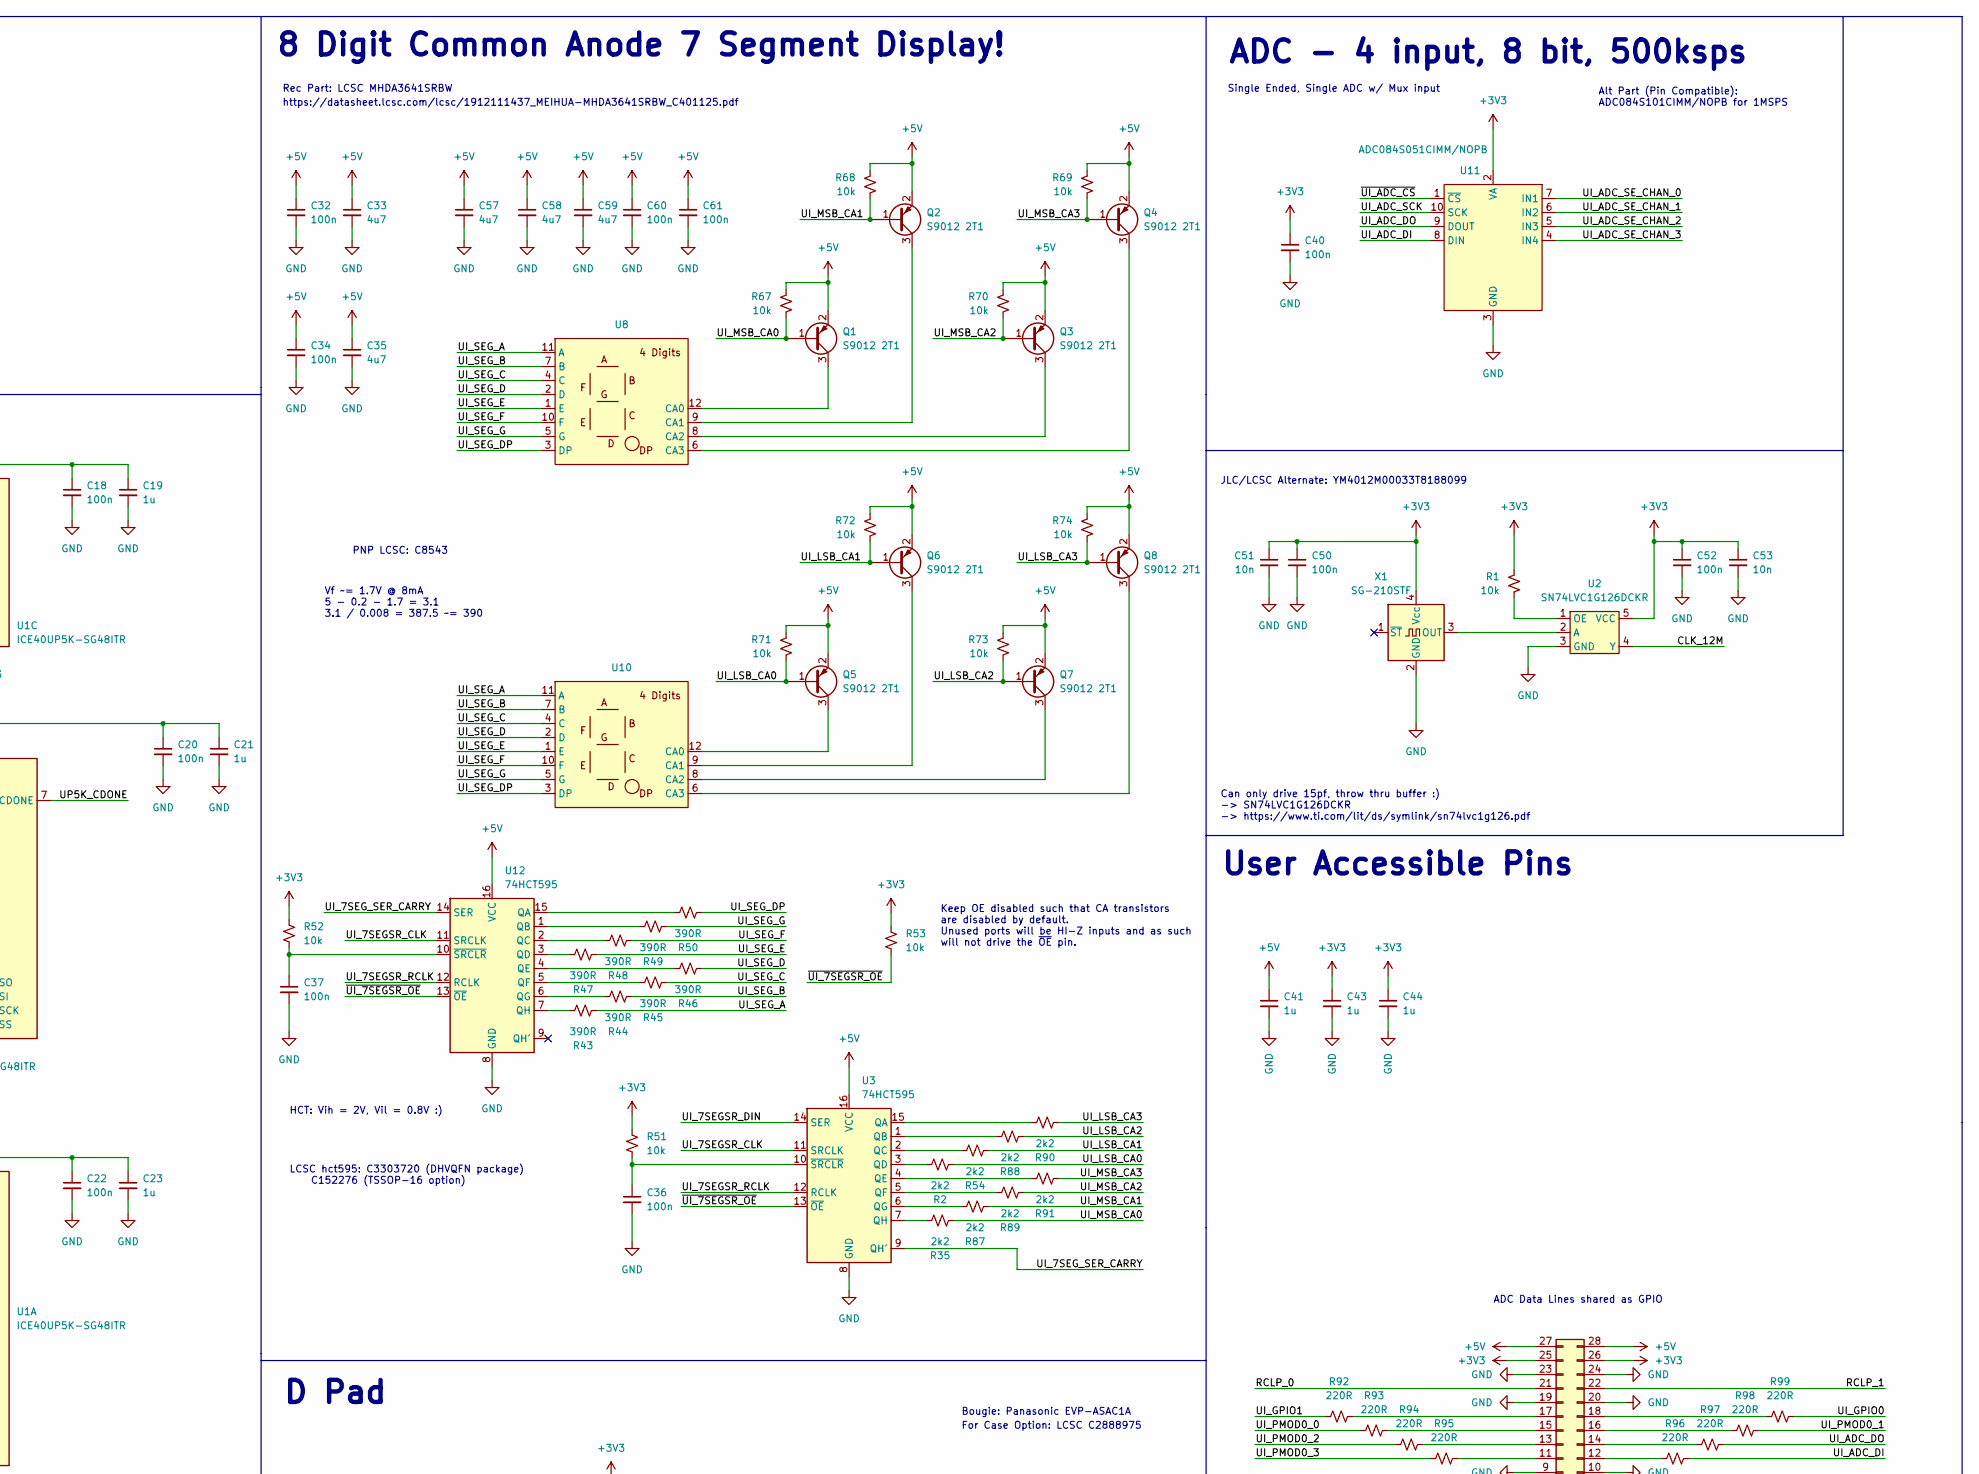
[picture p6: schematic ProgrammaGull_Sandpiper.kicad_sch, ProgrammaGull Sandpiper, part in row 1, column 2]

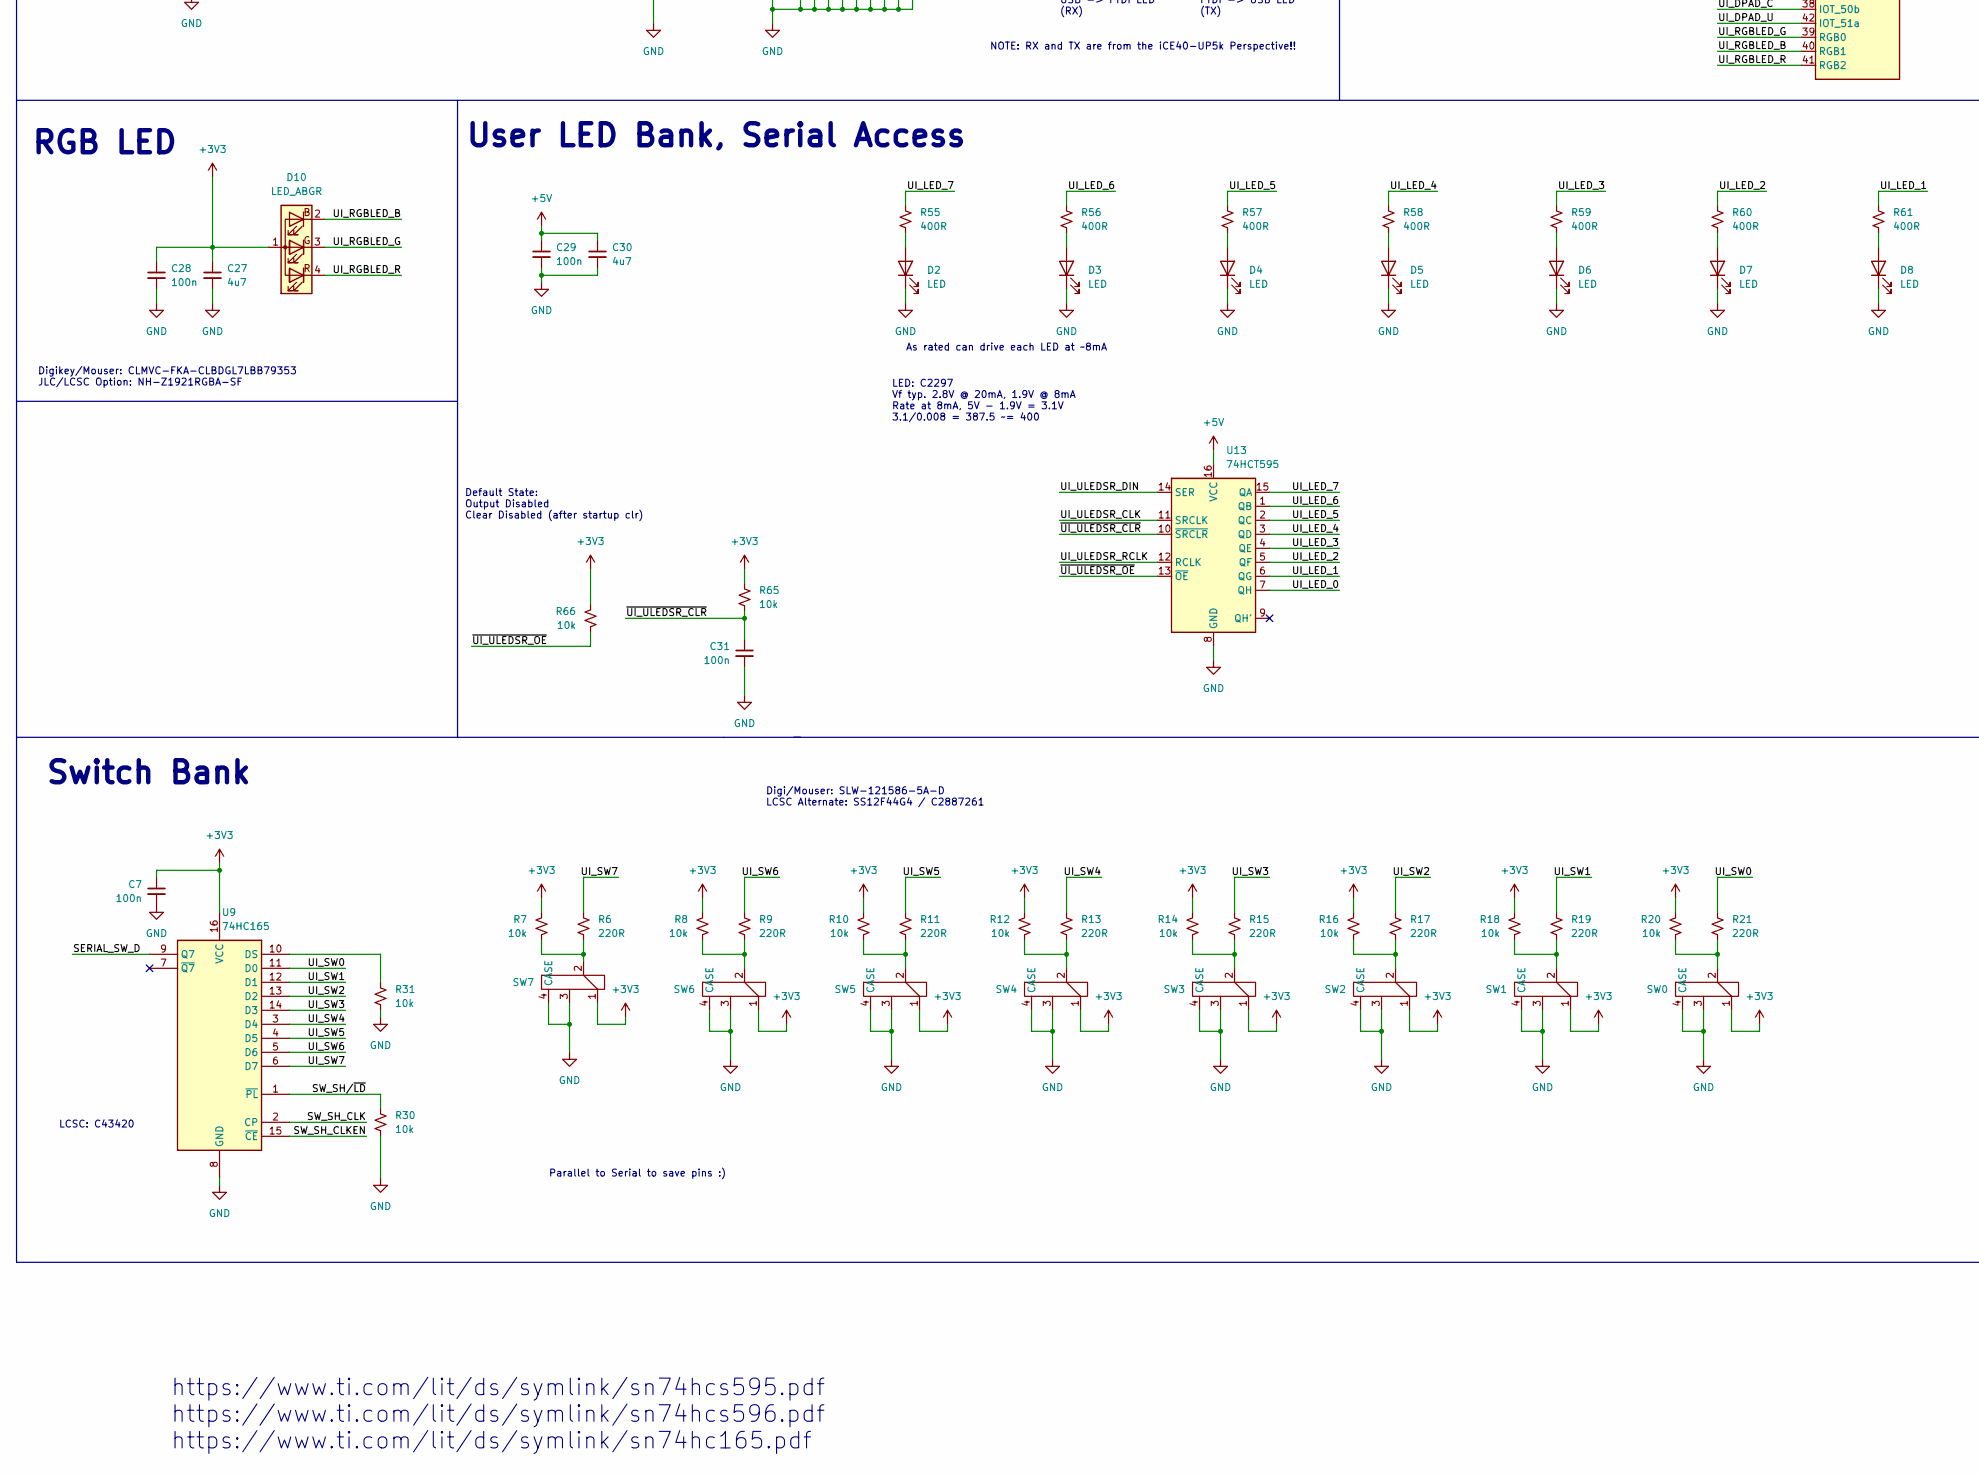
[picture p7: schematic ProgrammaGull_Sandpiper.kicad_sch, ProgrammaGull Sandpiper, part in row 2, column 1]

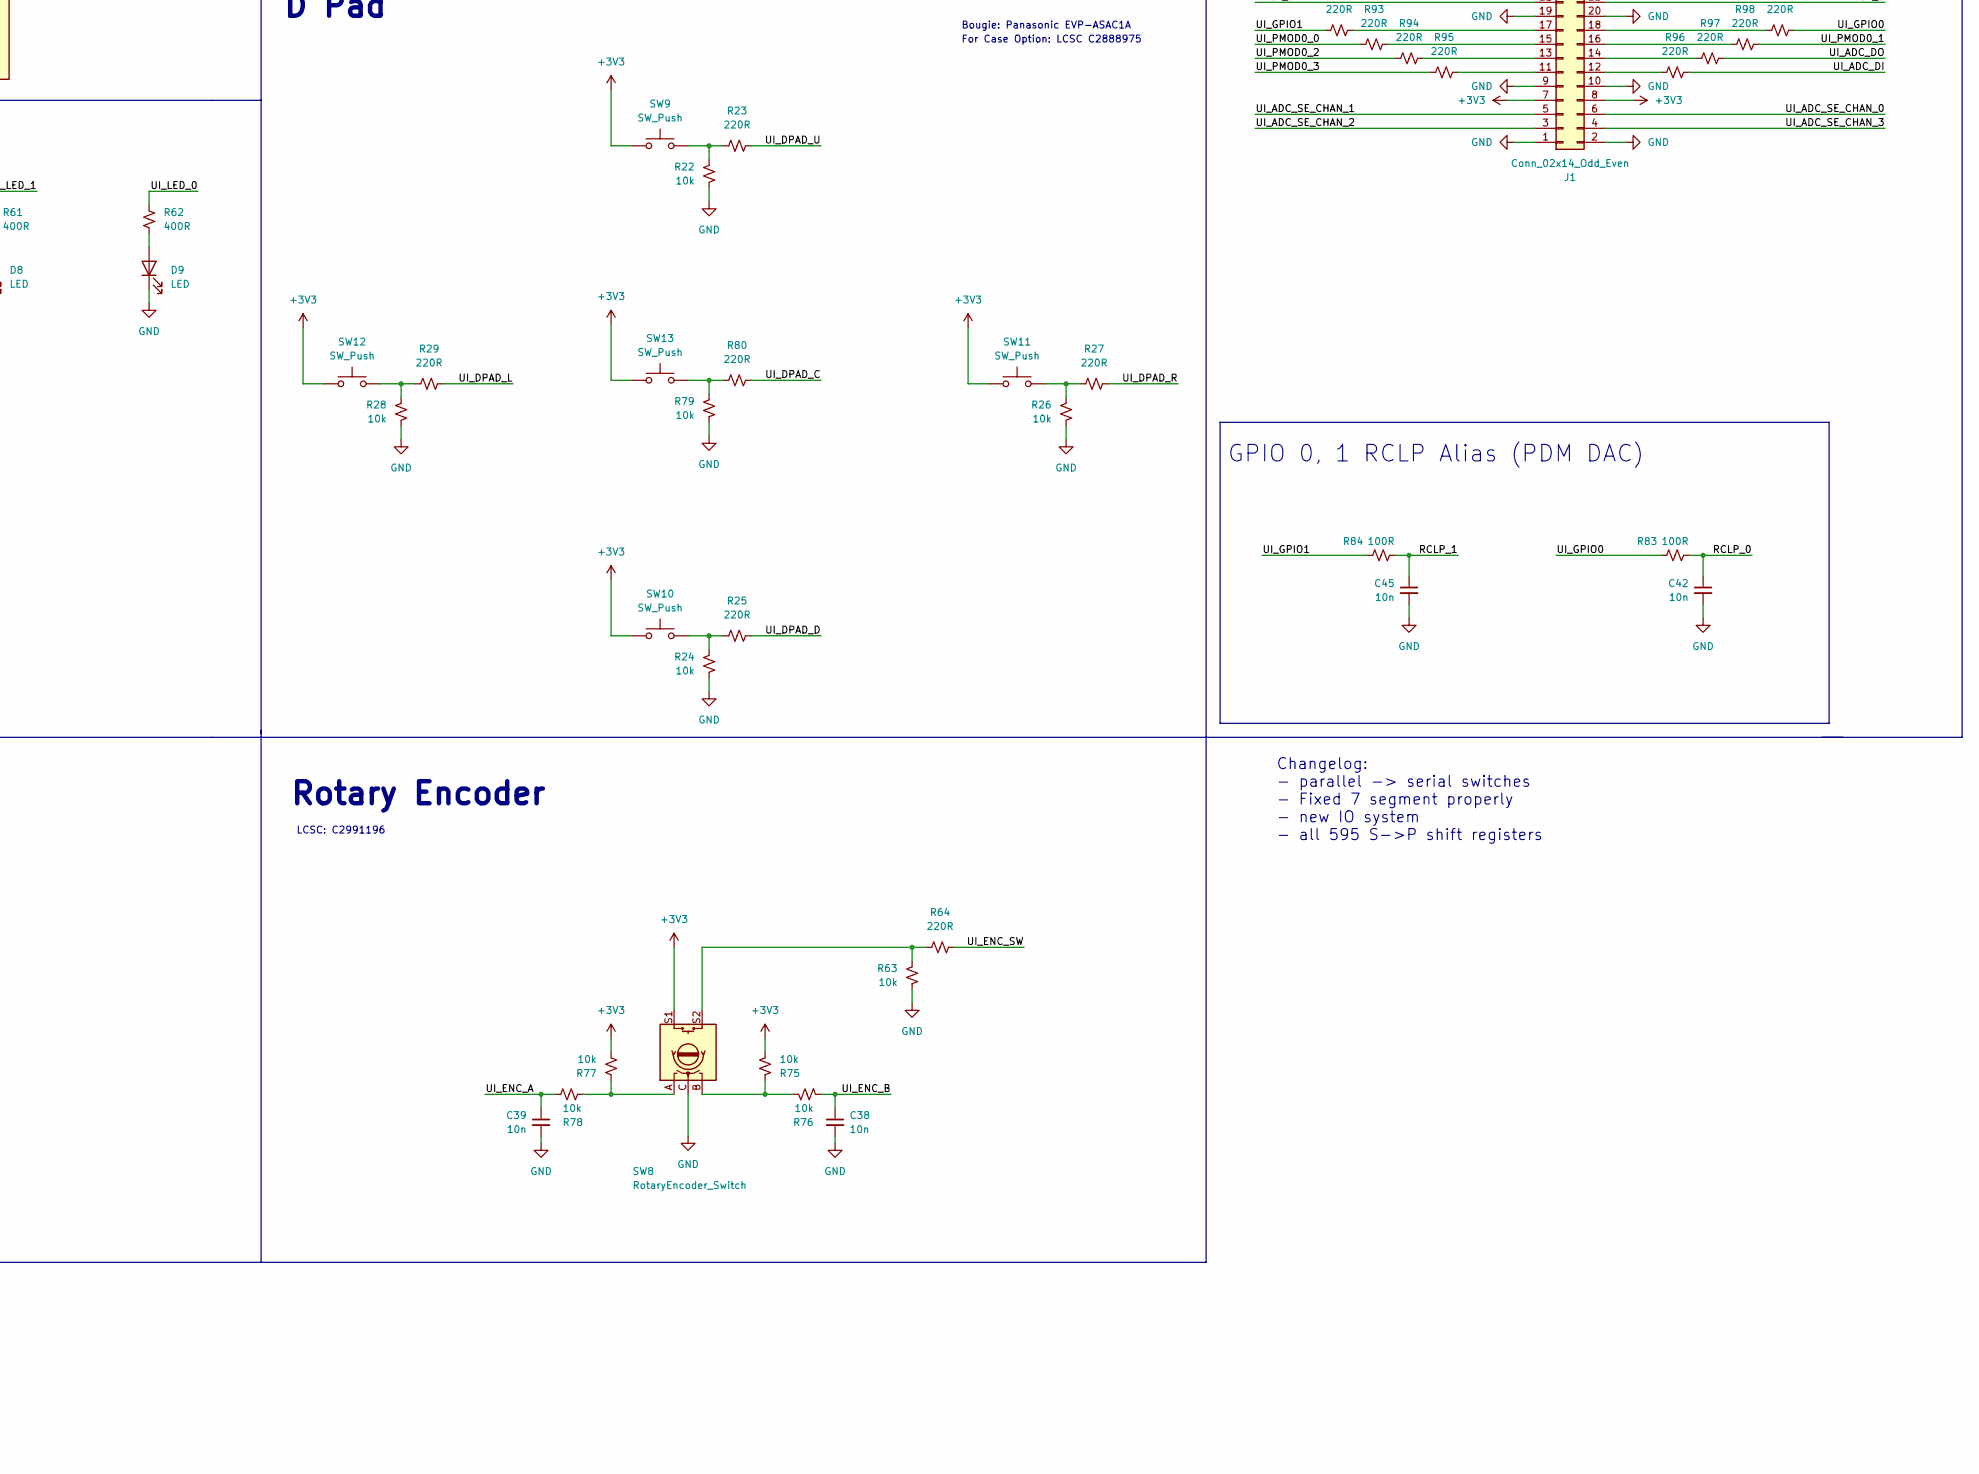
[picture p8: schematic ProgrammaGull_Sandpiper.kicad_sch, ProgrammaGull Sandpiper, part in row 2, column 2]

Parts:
C1, C2, C3, C4, C5, C6, C19, C21, C23, C24, C41, C43, C44: 1u; C_0603_1608Metric
C7, C8, C9, C11, C13, C14, C16, C18, C20, C22, C26, C28, C29, C31, C32, C34, C36, C37, C40, C46, C47, C48, C50, C52, C54, C55, C56, C60, C61: 100n; C_0603_1608Metric
C10, C12, C15, C17, C25, C27, C30, C33, C35, C57, C58, C59: 4u7; C_0805_2012Metric
C38, C39, C42, C45, C49, C51, C53: 10n; C_0603_1608Metric
D1: 1N4148W; D_SOD-123
D2, D3, D4, D5, D6, D7, D8, D9, D11, D12: LED; LED_0805_2012Metric
D10: LED_ABGR; LED_Cree-PLCC4_2x2mm_CW
FB1, FB2: FerriteBead_Small; L_0603_1608Metric
J1: Conn_02x14_Odd_Even; PinSocket_2x14_P2.54mm_Horizontal
P1: USB_C_Plug_USB2.0; USB_C_Receptacle_GCT_USB4105-xx-A_16P_TopMnt_Horizontal
Q1, Q2, Q3, Q4, Q5, Q6, Q7, Q8: S9012 2T1; SOT-23
R1, R7, R8, R10, R12, R14, R16, R18, R20, R22, R24, R26, R28, R30, R31, R32, R34, R36, R37, R39, R40, R41, R42, R51, R52, R53, R63, R65, R66, R67, R68, R69, R70, R71, R72, R73, R74, R75, R76, R77, R78, R79, R81: 10k; R_0603_1608Metric
R2, R33, R35, R54, R87, R88, R89, R90, R91: 2k2; R_0603_1608Metric
R3, R4: 56k; R_0603_1608Metric
R5, R83, R84: 100R; R_0603_1608Metric
R6, R9, R11, R13, R15, R17, R19, R21: 220R; R_0603_1608Metric
R23, R25, R27, R29, R64, R80, R92, R93, R94, R95, R96, R97, R98, R99: 220R; R_0402_1005Metric
R38: 12k 1%; R_0603_1608Metric
R43, R44, R45, R46, R47, R48, R49, R50: 390R; R_0603_1608Metric
R55, R56, R57, R58, R59, R60, R61, R62: 400R; R_0603_1608Metric
R85, R86: 330R; R_0603_1608Metric
SW0, SW1, SW2, SW3, SW4, SW5, SW6, SW7: SLW-121586-5A-D
SW8: RotaryEncoder_Switch; RotaryEncoder_Alps_EC11E-Switch_Vertical_H20mm
SW9, SW10, SW11, SW12, SW13: SW_Push; TSC015A05518A
U1: ICE40UP5K-SG48ITR; QFN-48-1EP_7x7mm_P0.5mm_EP5.6x5.6mm
U2: SN74LVC1G126DCKR; SC70
U3, U12, U13: 74HCT595; DHVQFN-16-1EP_2.5x3.5mm_P0.5mm_EP1x2mm
U4: MIC5504-1.2YM5; SOT-23-5
U5: MIC5504-2.5YM5; SOT-23-5
U6: 93LCxxAxxOT; SOT-23-6
U7: FT2232HQ; QFN-64-1EP_9x9mm_P0.5mm_EP4.35x4.35mm
U8, U10: MHDA3641SRBW
U9: 74HC165; TSSOP-16_4.4x5mm_P0.65mm
U11: ADC084S051CIMM/NOPB; VSSOP-10_3x3mm_P0.5mm
U14: W25Q32JVSS; SOIC-8_5.23x5.23mm_P1.27mm
U15: AMS1117-3.3; SOT-223-3_TabPin2
X1: SG-210STF; Oscillator_SMD_SeikoEpson_SG210-4Pin_2.5x2.0mm

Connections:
+1V2: C6.1, C48.1, C49.1, C56.1, R5.2, U1.5 (VCC), U1.30 (VCC), U4.5 (VOUT)
+2V5: C5.1, D1.1 (K), U1.24 (VPP_2V5), U5.5 (VOUT)
+5V: C1.1, C24.1, C25.1, C26.1, C29.1, C30.1, C32.1, C33.1, C34.1, C35.1, C41.1, C57.1, C58.1, C59.1, C60.1, C61.1, J1.27, J1.28, P1.A4 (VBUS), P1.A9 (VBUS), P1.B4 (VBUS), P1.B9 (VBUS), Q1.2 (E), Q2.2 (E), Q3.2 (E), Q4.2 (E), Q5.2 (E), Q6.2 (E), Q7.2 (E), Q8.2 (E), R67.2, R68.2, R69.2, R70.2, R71.2, R72.2, R73.2, R74.2, U3.16 (VCC), U12.16 (VCC), U13.16 (VCC), U15.3 (VI)
/CLK_12M: U1.37 (IOT_45a_G1), U2.4 (Y), U7.2 (OSCI)
/EEPROM_SPI_CLK: R36.1, U6.4 (CLK), U7.62 (EECLK)
/EEPROM_SPI_CS: R34.1, U6.5 (CS), U7.63 (EECS)
/EEPROM_SPI_DI: R33.2, U6.3 (DI), U7.61 (EEDATA)
/EEPROM_SPI_DO: R33.1, R37.1, U6.1 (DO)
/FLASH_CS: R32.1, U1.16 (IOB_35b_SPI_SS), U7.21 (ADBUS4), U14.1 (~CS)
/FLASH_MISO: U1.17 (IOB_33b_SPI_SI), U7.18 (ADBUS2), U14.2 (DO(IO1))
/FLASH_MOSI: U1.14 (IOB_32a_SPI_SO), U7.17 (ADBUS1), U14.5 (DI(IO0))
/FLASH_SCK: R42.1, U1.15 (IOB_34a_SPI_SCK), U7.16 (ADBUS0), U14.6 (CLK)
/RCLP_0: C42.1, J1.21, R83.1
/RCLP_1: C45.1, J1.22, R84.1
/SERIAL_SW_D: U1.32 (IOT_43a), U9.9 (Q7)
/SW_SH_CLK: U1.28 (IOT_41a), U9.2 (CP), U13.11 (SRCLK)
/SW_SH_CLKEN: U1.31 (IOT_42b), U9.15 (~CE)
/SW_SH/~LD: R30.2, U1.34 (IOT_44b), U9.1 (~PL)
/UI_7SEGSR_CLK: U1.13 (IOB_24a), U3.11 (SRCLK), U12.11 (SRCLK)
/UI_7SEGSR_DIN: U1.11 (IOB_20a), U3.14 (SER)
/UI_7SEGSR_RCLK: U1.12 (IOB_22a), U3.12 (RCLK), U12.12 (RCLK)
/UI_7SEG_SER_CARRY: U3.9 (QH'), U12.14 (SER)
/UI_ADC_DI: R96.1, U1.47 (IOB_2a), U11.8 (DIN)
/UI_ADC_DO: R97.1, U1.46 (IOB_0a), U11.9 (DOUT)
/UI_ADC_SCK: U1.45 (IOB_5b), U11.10 (SCK)
/UI_ADC_SE_CHAN_0: J1.6, U11.7 (IN1)
/UI_ADC_SE_CHAN_1: J1.5, U11.6 (IN2)
/UI_ADC_SE_CHAN_2: J1.3, U11.5 (IN3)
/UI_ADC_SE_CHAN_3: J1.4, U11.4 (IN4)
/UI_DPAD_C: R80.1, U1.38 (IOT_50b)
/UI_DPAD_D: R25.1, U1.36 (IOT_48b)
/UI_DPAD_L: R29.1, U1.35 (IOT_46b_G0)
/UI_DPAD_R: R27.1, U1.43 (IOT_49a)
/UI_DPAD_U: R23.1, U1.42 (IOT_51a)
/UI_ENC_A: C39.1, R78.1, U1.25 (IOT_36b)
/UI_ENC_B: C38.1, R76.1, U1.26 (IOT_39a)
/UI_ENC_SW: R64.1, U1.27 (IOT_38b)
/UI_GPIO0: R83.2, R99.1, U1.9 (IOB_16a)
/UI_GPIO1: R84.2, R92.2, U1.6 (IOB_13b)
/UI_LED_0: R62.2, U13.7 (QH)
/UI_LED_1: R61.2, U13.6 (QG)
/UI_LED_2: R60.2, U13.5 (QF)
/UI_LED_3: R59.2, U13.4 (QE)
/UI_LED_4: R58.2, U13.3 (QD)
/UI_LED_5: R57.2, U13.2 (QC)
/UI_LED_6: R56.2, U13.1 (QB)
/UI_LED_7: R55.2, U13.15 (QA)
/UI_LSB_CA0: Q5.1 (B), R2.1, R71.1
/UI_LSB_CA1: Q6.1 (B), R54.1, R72.1
/UI_LSB_CA2: Q7.1 (B), R73.1, R88.1
/UI_LSB_CA3: Q8.1 (B), R74.1, R90.1
/UI_MSB_CA0: Q1.1 (B), R35.1, R67.1
/UI_MSB_CA1: Q2.1 (B), R68.1, R87.1
/UI_MSB_CA2: Q3.1 (B), R70.1, R89.1
/UI_MSB_CA3: Q4.1 (B), R69.1, R91.1
/UI_PMOD0_0: R93.2, U1.4 (IOB_8a)
/UI_PMOD0_1: R98.1, U1.3 (IOB_9b)
/UI_PMOD0_2: R94.2, U1.2 (IOB_6a)
/UI_PMOD0_3: R95.2, U1.48 (IOB_4a)
/UI_RGBLED_B: D10.2 (BK), U1.40 (RGB1)
/UI_RGBLED_G: D10.3 (GK), U1.39 (RGB0)
/UI_RGBLED_R: D10.4 (RK), U1.41 (RGB2)
/UI_SEG_A: R43.1, U8.11 (A), U10.11 (A)
/UI_SEG_B: R44.1, U8.7 (B), U10.7 (B)
/UI_SEG_C: R45.1, U8.4 (C), U10.4 (C)
/UI_SEG_D: R46.1, U8.2 (D), U10.2 (D)
/UI_SEG_DP: R50.1, U8.3 (DP), U10.3 (DP)
/UI_SEG_E: R47.1, U8.1 (E), U10.1 (E)
/UI_SEG_F: R48.1, U8.10 (F), U10.10 (F)
/UI_SEG_G: R49.1, U8.5 (G), U10.5 (G)
/UI_SW0: R21.2, U9.11 (D0)
/UI_SW1: R19.2, U9.12 (D1)
/UI_SW2: R17.2, U9.13 (D2)
/UI_SW3: R15.2, U9.14 (D3)
/UI_SW4: R13.2, U9.3 (D4)
/UI_SW5: R11.2, U9.4 (D5)
/UI_SW6: R9.2, U9.5 (D6)
/UI_SW7: R6.2, U9.6 (D7)
/UI_ULEDSR_DIN: U1.20 (IOB_25b_G3), U13.14 (SER)
/UI_ULEDSR_RCLK: U1.23 (IOT_37a), U13.12 (RCLK)
/UP5K_CDONE: U1.7 (CDONE), U7.23 (ADBUS6)
/UP5K_CRESET: R81.1, U1.8 (~CRESET), U7.24 (ADBUS7)
/UP5K_UART_CTS: U7.41 (BDBUS3)
/UP5K_UART_DCD: U7.45 (BDBUS6)
/UP5K_UART_DSR: U7.44 (BDBUS5)
/UP5K_UART_DTR: U7.43 (BDBUS4)
/UP5K_UART_RTS: U7.40 (BDBUS2)
/UP5K_UART_RX: U1.19 (IOB_29b), U7.38 (BDBUS0)
/UP5K_UART_TX: U1.18 (IOB_31b), U7.39 (BDBUS1)
/USB_CC: P1.A5 (CC), R3.2
/USB_D+: P1.A6 (D+), U7.8 (DP)
/USB_D-: P1.A7 (D-), U7.7 (DM)
/USB_VCONN: P1.B5 (VCONN), R4.2
/~UI_7SEGSR_OE: R53.1, U1.10 (IOB_18a), U3.13 (~OE), U12.13 (~OE)
/~UI_ADC_CS: U1.44 (IOB_3b_G6), U11.1 (~CS)
/~UI_ULEDSR_CLR: C31.1, R65.1, U13.10 (~SRCLR)
/~UI_ULEDSR_OE: R66.1, U1.21 (IOB_23b), U13.13 (~OE)
GND: C1.2, C2.2, C3.2, C4.2, C5.2, C6.2, C7.2, C8.2, C9.2, C10.2, C11.2, C12.2, C13.2, C14.2, C15.2, C16.2, C17.2, C18.2, C19.2, C20.2, C21.2, C22.2, C23.2, C24.2, C25.2, C26.2, C27.2, C28.2, C29.2, C30.2, C31.2, C32.2, C33.2, C34.2, C35.2, C36.2, C37.2, C38.2, C39.2, C40.2, C41.2, C42.2, C43.2, C44.2, C45.2, C46.2, C47.2, C48.2, C49.2, C50.2, C51.2, C52.2, C53.2, C54.2, C55.2, C56.2, C57.2, C58.2, C59.2, C60.2, C61.2, D2.1 (K), D3.1 (K), D4.1 (K), D5.1 (K), D6.1 (K), D7.1 (K), D8.1 (K), D9.1 (K), J1.1, J1.2, J1.9, J1.10, J1.19, J1.20, J1.23, J1.24, P1.A1 (GND), P1.A12 (GND), P1.B1 (GND), P1.B12 (GND), P1.S1 (SHIELD), R3.1, R4.1, R22.1, R24.1, R26.1, R28.1, R30.1, R31.1, R38.1, R63.1, R79.1, SW0.3, SW0.4 (CASE), SW1.3, SW1.4 (CASE), SW2.3, SW2.4 (CASE), SW3.3, SW3.4 (CASE), SW4.3, SW4.4 (CASE), SW5.3, SW5.4 (CASE), SW6.3, SW6.4 (CASE), SW7.3, SW7.4 (CASE), SW8.C, U1.49 (GND), U2.3 (GND), U3.8 (GND), U4.2 (GND), U5.2 (GND), U6.2 (GND), U7.1 (GND), U7.5 (GND), U7.10 (AGND), U7.11 (GND), U7.13 (TEST), U7.15 (GND), U7.25 (GND), U7.35 (GND), U7.47 (GND), U7.51 (GND), U7.65 (GND), U9.8 (GND), U11.3 (GND), U12.8 (GND), U13.8 (GND), U14.4 (GND), U15.1 (GND), X1.2 (GND); also elsewhere on the board
unnamed: D2.2 (A), R55.1
unnamed: D3.2 (A), R56.1
unnamed: D4.2 (A), R57.1
unnamed: D5.2 (A), R58.1
unnamed: D6.2 (A), R59.1
unnamed: D7.2 (A), R60.1
unnamed: D8.2 (A), R61.1
unnamed: D9.2 (A), R62.1
unnamed: D11.1 (K), R85.1
unnamed: D12.1 (K), R86.1
unnamed: J1.11, R95.1
unnamed: J1.12, R96.2
unnamed: J1.13, R94.1
unnamed: J1.14, R97.2
unnamed: J1.15, R93.1
unnamed: J1.16, R98.2
unnamed: J1.17, R92.1
unnamed: J1.18, R99.2
unnamed: Q1.3 (C), U8.12 (CA0)
unnamed: Q2.3 (C), U8.9 (CA1)
unnamed: Q3.3 (C), U8.8 (CA2)
unnamed: Q4.3 (C), U8.6 (CA3)
unnamed: Q5.3 (C), U10.12 (CA0)
unnamed: Q6.3 (C), U10.9 (CA1)
unnamed: Q7.3 (C), U10.8 (CA2)
unnamed: Q8.3 (C), U10.6 (CA3)
unnamed: R6.1, R7.1, SW7.2
unnamed: R8.1, R9.1, SW6.2
unnamed: R10.1, R11.1, SW5.2
unnamed: R12.1, R13.1, SW4.2
unnamed: R14.1, R15.1, SW3.2
unnamed: R16.1, R17.1, SW2.2
unnamed: R18.1, R19.1, SW1.2
unnamed: R20.1, R21.1, SW0.2
unnamed: R22.2, R23.2, SW9.2
unnamed: R24.2, R25.2, SW10.2
unnamed: R26.2, R27.2, SW11.2
unnamed: R28.2, R29.2, SW12.2
unnamed: R63.2, R64.2, SW8.S2
unnamed: R75.2, R76.2, SW8.B
unnamed: R77.2, R78.2, SW8.A
unnamed: R79.2, R80.2, SW13.2
unnamed: C8.1, R5.1, U1.29 (VCCPLL)
unnamed: U2.2 (A), X1.3 (OUT)
unnamed: R1.1, U2.1 (OE)
unnamed: R90.2, U3.15 (QA)
unnamed: R88.2, U3.1 (QB)
unnamed: R54.2, U3.2 (QC)
unnamed: R2.2, U3.3 (QD)
unnamed: R91.2, U3.4 (QE)
unnamed: R89.2, U3.5 (QF)
unnamed: R87.2, U3.6 (QG)
unnamed: R35.2, U3.7 (QH)
unnamed: C36.1, R51.1, U3.10 (~SRCLR)
unnamed: R86.2, U7.54 (BCBUS3)
unnamed: R85.2, U7.55 (BCBUS4)
unnamed: R38.2, U7.6 (REF)
unnamed: C14.1, C15.1, FB2.1, U7.4 (VPHY)
unnamed: C12.1, C13.1, FB1.1, U7.9 (VPLL)
unnamed: R39.1, U7.14 (~RESET)
unnamed: R31.2, U9.10 (DS)
unnamed: R50.2, U12.15 (QA)
unnamed: R49.2, U12.1 (QB)
unnamed: R48.2, U12.2 (QC)
unnamed: R47.2, U12.3 (QD)
unnamed: R46.2, U12.4 (QE)
unnamed: R45.2, U12.5 (QF)
unnamed: R44.2, U12.6 (QG)
unnamed: R43.2, U12.7 (QH)
unnamed: C37.1, R52.1, U12.10 (~SRCLR)
unnamed: R40.1, U14.3 (IO2)
unnamed: R41.1, U14.7 (IO3)

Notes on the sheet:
LED: C2297 Vf typ. 2.8V @ 20mA, 1.9V @ 8mA Rate at 8mA, 5V - 1.9V = 3.1V 3.1/0.008 = 387.5 ~= 400
FTDI -> USB LED (TX)
SPI Flash
PNP LCSC: C8543
User Accessible Pins
Slanted to annoy Alec :)
Keep OE disabled such that CA transistors are disabled by default. Unused ports will be HI-Z inputs and as such will not drive the ~{OE} pin.
Serial UI Bank: User LED Bank 7 Segment Display
Changelog: - parallel -> serial switches - Fixed 7 segment properly - new IO system - all 595 S->P shift registers
For Case Option: LCSC C2888975
Digikey/Mouser: CLMVC-FKA-CLBDGL7LBB79353 JLC/LCSC Option: NH-Z1921RGBA-SF
ADC - 4 input, 8 bit, 500ksps
Alt Part (Pin Compatible): ADC084S101CIMM/NOPB for 1MSPS
Removed MIC5504 3V3 for more current capacity
LCSC: C2991196
LCSC hct595: C3303720 (DHVQFN package) C152276 (TSSOP-16 option)
FPGA Core Power
Rotary Encoder
RGB LED
LC Filter action as recommended in datasheet
Vf ~= 1.7V @ 8mA 5 - 0.2 - 1.7 = 3.1 3.1 / 0.008 = 387.5 ~= 390
https://datasheet.lcsc.com/lcsc/1912111437_MEIHUA-MHDA3641SRBW_C401125.pdf
As rated can drive each LED at ~8mA
HCT: Vih = 2V, Vil = 0.8V :)
Bougie: Panasonic EVP-ASAC1A
Digi/Mouser: SLW-121586-5A-D LCSC Alternate: SS12F44G4 / C2887261
NOTE: RX and TX are from the iCE40-UP5k Perspective!!
8 Digit Common Anode 7 Segment Display!
USB -> FTDI LED (RX)
FPGA Pinout
GPIO 0, 1 RCLP Alias (PDM DAC)
Parallel to Serial to save pins :)
User LED Bank, Serial Access
EXT CLK
UI Bank: Switches Buttons RGB LED
Can only drive 15pf, throw thru buffer :) -> SN74LVC1G126DCKR -> https://www.ti.com/lit/ds/symlink/sn74lvc1g126.pdf
Rec Part: LCSC MHDA3641SRBW
https://www.ti.com/lit/ds/symlink/sn74hcs595.pdf https://www.ti.com/lit/ds/symlink/sn74hcs596.pdf https://www.ti.com/lit/ds/symlink/sn74hc165.pdf
Switch Bank
USB Prog and VCOM

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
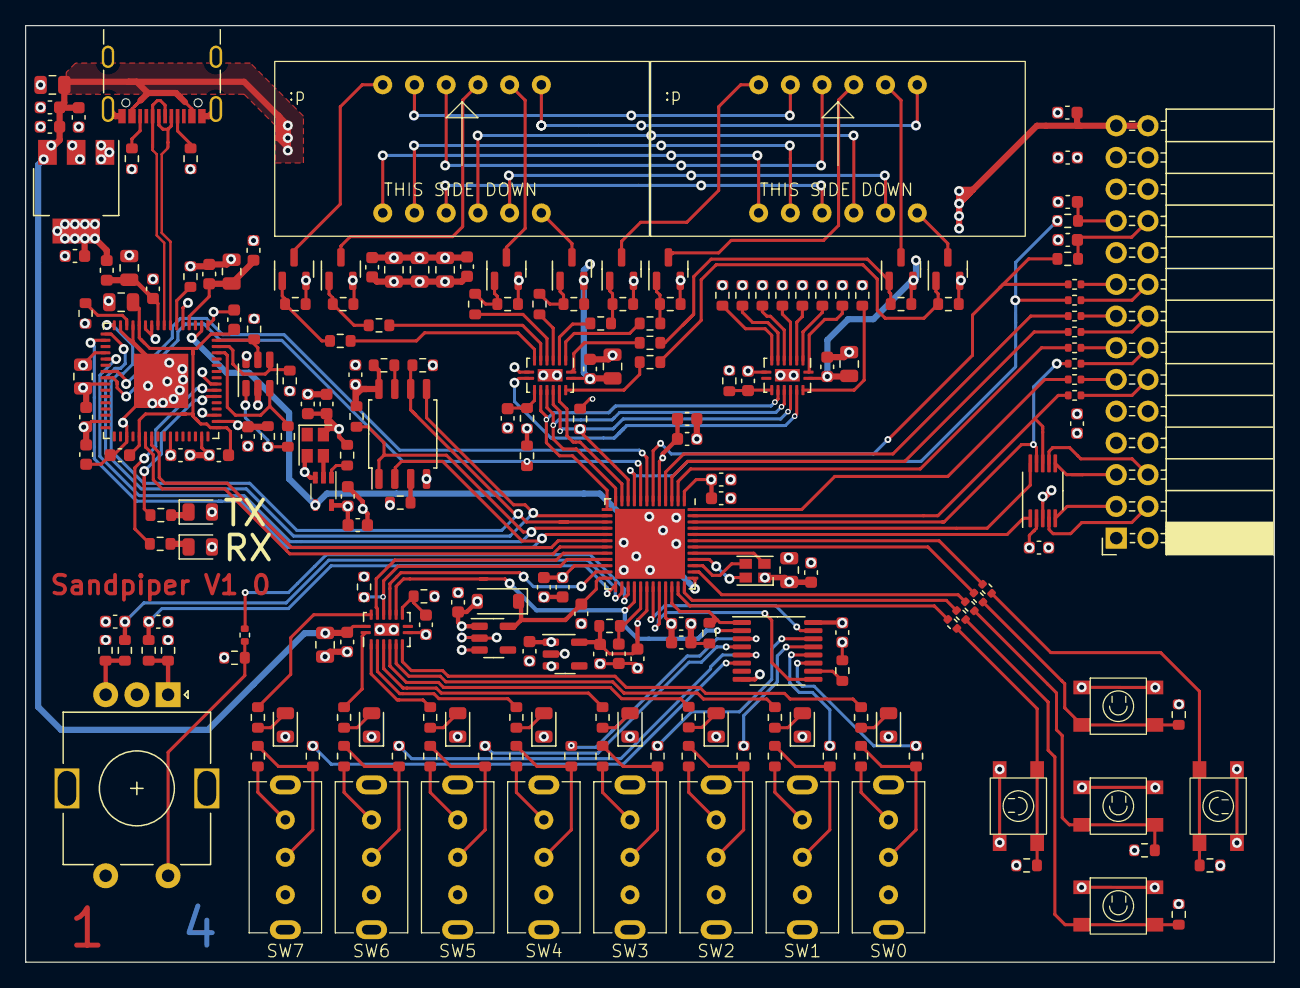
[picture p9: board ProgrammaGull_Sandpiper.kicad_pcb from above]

Board: 4 copper layers, 100.0 x 75.0 mm, 214 parts (0 on the bottom side), 167 nets.

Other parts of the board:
C46#2: 100n; C_0603_1608Metric

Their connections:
GND: C46#2.2; also elsewhere on the board

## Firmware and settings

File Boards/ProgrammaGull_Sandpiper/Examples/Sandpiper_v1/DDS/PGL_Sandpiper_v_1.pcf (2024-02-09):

#####################################
# Flash and FTDI Interface 0        #
set_io -nowarn FLASH_SCK	    15  #
set_io -nowarn FLASH_CSN	    16	# Drive high if not connected to flash.
set_io -nowarn FLASH_MISO	    17	# May need to flip MISO/MOSI perspectives
set_io -nowarn FLASH_MOSI	    14  #
                                    #
set_io -nowarn UART_RX		    19  # Data being sent FROM the FTDI to iCE40
set_io -nowarn UART_TX		    18  # Data being sent FROM the iCE40 to FTDI
#####################################

#####################################
# Bank 0: User Input, Bank 0, 3V3   #
set_io -nowarn UI_ENC_BUTTON	27  # Encoder Button is:
set_io -nowarn UI_ENC_A	        25  #   LOW when unpressed
set_io -nowarn UI_ENC_B     	26  #   HIGH when pressed
                                    #   
set_io -nowarn UI_DPAD_L	    35  # All DPAD Button Positions:
set_io -nowarn UI_DPAD_R	    43  #   NO = Low, MOM = HIGH
set_io -nowarn UI_DPAD_D	    36  #
set_io -nowarn UI_DPAD_U	    42  #
set_io -nowarn UI_DPAD_C	    38  #
                                    #
set_io -nowarn UI_SW_D		    32  # All Switch Positions:
set_io -nowarn UI_SW_CLKEN		31  #   UP = HIGH, DOWN = LOW
set_io -nowarn UI_SW_ULED_CLK   28  #   Switches are shifted in!
set_io -nowarn UI_SW_SH_LD      34  #
#####################################

#####################################
# External Clock, Bank 0, 3V3       #
set_io -nowarn CLK_12MHZ	    37  # Ties directly into Global Buffer 1
#####################################

#####################################
# 7 Segment Display, Common Anode   # 
set_io -nowarn UI_7SEGSR_CLK	13  #
set_io -nowarn UI_7SEGSR_RCLK	12  #
set_io -nowarn UI_7SEGSR_DIN	11  #
set_io -nowarn UI_7SEGSR_OE	    10  # LOW = Output Enabled, HIGH = Disabled
#####################################

#####################################
# 8 LED Array                       #
# Note:                             #
#   Shift register clock shared     #
#   with UI_SW shift register       #
#                                   #
set_io -nowarn UI_ULEDSR_OE	    21  #
set_io -nowarn UI_ULEDSR_DIN	20  #
#####################################

#####################################
# GPIO, Bank 1, 3V3                 #
set_io -nowarn UI_GPIO_0	    6   # Low Pass Alias on board for PDM
set_io -nowarn UI_GPIO_1	    9   # ^
#####################################

#####################################
# ADC SPI Interface, Bank 2, 3V3    #
set_io -nowarn UI_ADC_CSN	    44  #
set_io -nowarn UI_ADC_SCK	    45  #
set_io -nowarn UI_ADC_DI	    47  #
set_io -nowarn UI_ADC_DO	    46  #
#####################################

#####################################
# PMOD 0, Bank 2, 3V3               # 
#   1x6 pin Version                 #
set_io -nowarn UI_PMOD0_0	    4   #
set_io -nowarn UI_PMOD0_1	    3   #
set_io -nowarn UI_PMOD0_2	    2   #
set_io -nowarn UI_PMOD0_3	    48  #
#####################################

#####################################
# Common Anode RGB LED              #
# Wired to Lattice RGB LED Driver   #
set_io -nowarn UI_RGBLED_R	    41  #
set_io -nowarn UI_RGBLED_G	    39  #
set_io -nowarn UI_RGBLED_B	    40  #
#####################################

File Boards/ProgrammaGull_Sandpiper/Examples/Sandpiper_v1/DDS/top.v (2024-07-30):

module SANDPIPER_DDS (
    input CLK_12MHZ,

    // DPAD
    input UI_DPAD_U,
    input UI_DPAD_D,
    input UI_DPAD_C,

    // Arr Gee Bee
    output UI_RGBLED_R,
    output UI_RGBLED_G,
    output UI_RGBLED_B,

    // RCLP DAC Output
    output UI_GPIO_1,

    // 7 Segment Shift Register
    output          UI_7SEGSR_CLK,
    output          UI_7SEGSR_RCLK,
    output          UI_7SEGSR_DIN,
    output          UI_7SEGSR_OE
);

    reg pll_50MHz;
    reg pll_25MHz;
    wire PLL_LOCK;
    assign UI_RGBLED_B = ~(PLL_LOCK & CLK_12MHZ);
    wire pll_100MHz;
    ice_pll pll_100MHz_src (
        .pll_clk_src(CLK_12MHZ),
        .PLL_LOCK(PLL_LOCK),
        .pll_clk_out(pll_100MHz)
    );


    wire [7:0]bram_addr_bus;
    reg [15:0]divvy;
    NCO #(
        .DIV_W(16),
        .ADDR_W(8)
    ) nco (
        .sys_clk(pll_50MHz),
        .en(PLL_LOCK),
        .divider(divvy),
        .address(bram_addr_bus)
    );


    wire up_button;
    button_debouncer #(
        .SYSCLK_FREQ(50000000)
    ) up_button_inst (
        .clk(pll_50MHz),
        .D(UI_DPAD_U),
        .Q(up_button)
    );

    wire dn_button;
    button_debouncer #(
        .SYSCLK_FREQ(50000000)
    ) dn_button_inst (
        .clk(pll_50MHz),
        .D(UI_DPAD_D),
        .Q(dn_button)
    );

    wire ct_button;
    button_debouncer #(
        .SYSCLK_FREQ(50000000)
    ) ct_button_inst (
        .clk(pll_50MHz),
        .D(UI_DPAD_C),
        .Q(ct_button)
    );

    reg [7:0]bram_addr_pl;
    wire [15:0]bram_data;
    sin_bram #(
        .DATA_W(16),
        .SAMPLE_CT(256),
        .SAMPLE_ADDR_BITS(8)
    ) sinlut (
        .bram_clk(pll_50MHz),
        .bram_ce(1'b1),
        .bram_addr(bram_addr_pl),
        .bram_out(bram_data)
    );

    fods_mod #(
        .DATA_W(16)
    ) ddsout (
        .mod_clk(pll_100MHz),
        .mod_din(bram_data),
        .mod_dout(UI_GPIO_1)
    );

/*
module num_2_seg 
#(
    parameter SYSCLK_F = 24000000,
    parameter MAX_DIGITS = 5,
    parameter ASCII_LUT_SIZE = 256
) (
    input   en,
    input   cvt_num,
    input   sys_clk,

    input   [(INPUT_W - 1):0] inputval,

    output reg [($clog2(CAN_CT) - 1):0] an_sel,         // selected anode/character
    output reg [($clog2(ASCII_LUT_SIZE) - 1):0] ascii_lut_addr, // Address for Ascii LUT
    output reg commit,                                   // write values to 7 seg driver
    output reg cvt_in_prog
);
*/
    wire commit_from_n2s;
    wire [7:0] numeric_char_addr;
    wire [2:0] numeric_an_sel;
    num_2_seg n2s_inst (
        .en(1'b1),
        .cvt_num(dn_button || up_button),
        .sys_clk(pll_25MHz),
        .inputval(divvy),
        .an_sel(numeric_an_sel),
        .ascii_lut_addr(numeric_char_addr),
        .commit(commit_from_n2s)
    );


    wire [7:0] segbus;
    char_2_seg_LUT_8x512 c2s (
        .bram_clk(pll_25MHz),
        .bram_ce(1'b1),
        .bram_addr(numeric_char_addr),
        .bram_out(segbus)
    );

    PGL_Sandpiper_vAlpha_7Seg_Driver #(
        .SYSCLK_F(25000000)
    ) display_inst (
        .en(1'b1),
        .sys_clk(pll_25MHz),
        .clear_buffer(ct_button),
        .commit_char(commit_from_n2s),
        .SEGMENTS_2_LIGHT(segbus),
        .CHAR_SELECTED(numeric_an_sel),
        .CHAR_BRIGHTNESS(8'hFF),

        .SCLK(UI_7SEGSR_CLK),
        .DOUT(UI_7SEGSR_DIN),
        .RCLK(UI_7SEGSR_RCLK),
        .OE(UI_7SEGSR_OE)
    );



    reg redled;
    reg greenled;
    assign UI_RGBLED_G = ~greenled;
    assign UI_RGBLED_R = ~redled;

    initial begin
        bram_addr_pl   = 0;
        divvy       = 0;
        pll_50MHz   = 0;
        pll_25MHz   = 0;
        enable      = 0;

        redled      = 0;
        greenled    = 0;
    end

    always @ (posedge pll_100MHz) begin
        pll_50MHz   <= ~pll_50MHz;
    end

    always @ (posedge pll_50MHz) begin
        pll_25MHz   <= ~pll_25MHz;
    //    bram_addr <= bram_addr + 1;
        if(dn_button && !up_button) begin
            divvy <= divvy - 1;
            redled      <= !redled;
            greenled    <= 0;
        end
        else if(up_button && !dn_button) begin
            divvy <= divvy + 1;
            redled      <= 0;
            greenled    <= !greenled;
        end
        //if(UI_DPAD_D && !UI_DPAD_U) divvy <= divvy - 1;
        //if(UI_DPAD_U && !UI_DPAD_D) divvy <= divvy + 1;
        bram_addr_pl    <= bram_addr_bus;
    end
endmodule

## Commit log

2023-09-16 Initial E3 commit
    [ProgrammaGull_E3.kicad_pcb, ProgrammaGull_E3.kicad_sch]
2023-10-30 Initial Sandpiper Commit
    [ProgrammaGull_E3.kicad_pcb, ProgrammaGull_E3.kicad_sch, ProgrammaGull_Sandpiper.kicad_pcb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]
2023-11-01 Big Sandpiper updates :)
    [ProgrammaGull_Sandpiper.kicad_sch]
2023-11-01 Sandpiper Progress!
    [ProgrammaGull_Sandpiper.kicad_sch]
2023-11-06 Alpha Sandpiper Board Completegit status
    [ProgrammaGull_Sandpiper.kicad_pcb, ProgrammaGull_Sandpiper.kicad_sch]
2023-11-07 Fixed 7 segment drive circuitry to work properly, swap to 74 596 + segment brightness limiting resistors
    [ProgrammaGull_Sandpiper.kicad_pcb, ProgrammaGull_Sandpiper.kicad_sch]
2023-11-08 Adjustments made to better fit JLC/LCSC Parts Library
    [ProgrammaGull_Sandpiper.kicad_sch]
2023-11-09 Final Alpha Version
    [ProgrammaGull_Sandpiper-B_Cu.gbr, ProgrammaGull_Sandpiper-B_Mask.gbr, ProgrammaGull_Sandpiper-B_Paste.gbr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]
2023-11-10 Final Sandpiper Alpha Changes, just cleanup.
    [ProgrammaGull_Sandpiper.kicad_pcb]
2023-11-15 Updated gitignore
    [ProgrammaGull_Sandpiper_BOM.csv, ProgrammaGull_Sandpiper_JLC_Final.csv, ProgrammaGull_Sandpiper_w_Sources.csv]
2023-11-15 Added PGL E6 project files, Sandpiper Alpha Schematic
    [ProgrammaGull_E6.kicad_pcb, ProgrammaGull_E6.kicad_sch]
2023-11-18 Errata: Fixed reversed LEDs on FTDI.... oops :)
    [ProgrammaGull_Sandpiper.kicad_pcb, ProgrammaGull_Sandpiper.kicad_sch]
2023-11-18 Updated board revision for Alpha
    [ProgrammaGull_Sandpiper.kicad_pcb]
2023-11-25 Minor Adds, small fixes on Sandpiper PCB
    [ProgrammaGull_Sandpiper.kicad_pcb]
2023-11-26 Hardware issue found with Sandpiper 7 Seg PNP array, looking into it
    [switch_2_led_array.v, top.v]
2023-11-27 Converted to 3v3 7 segment drive voltage
    [ProgrammaGull_Sandpiper.kicad_pcb, ProgrammaGull_Sandpiper.kicad_sch]
2023-11-27 Sandpiper Alpha Schematic updated for new 7 segment drive strategy
    [ProgrammaGull_Sandpiper.kicad_pcb]
2023-11-27 Small fixes in example
    [top.v]
2024-01-07 Sandpiper first release almost done :)
    [ProgrammaGull_Sandpiper.kicad_pcb, ProgrammaGull_Sandpiper.kicad_sch, ProgrammaGull_SandpiperBONRES.csv]
2024-01-22 Final revision Sandpiper V1, sent for fab
    [ProgrammaGull_Sandpiper-B_Cu.gbr, ProgrammaGull_Sandpiper-B_Mask.gbr, ProgrammaGull_Sandpiper-B_Paste.gbr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]
2024-02-06 Updated Sandpiper V1 PCF to match schematic
2024-02-09 Added PGL FT2232HQ generic programmer :)
    [PGL_FTDI_Prog.kicad_pcb, PGL_FTDI_Prog.kicad_sch]
2024-02-12 PGL Programmer Test Run Finished
    [PGL_FTDI_Prog-B_Cu.gbr, PGL_FTDI_Prog-B_Mask.gbr, PGL_FTDI_Prog-B_Paste.gbr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]
2024-02-13 Skimmer init
    [PGL_Skimmer.kicad_pcb, PGL_Skimmer.kicad_sch]
2024-02-15 Expanding device drivers for Sandpiper V1
2024-02-20 Added Sandpiper V1 DDS Example, currently only variable frequency sine
2024-07-31 PGL E3 Start
    [ProgrammaGull_E6.kicad_pcb, ProgrammaGull_E6.kicad_sch]
2024-08-06 E6 layout redo
    [ProgrammaGull_E6.kicad_pcb, ProgrammaGull_E6.kicad_sch]
